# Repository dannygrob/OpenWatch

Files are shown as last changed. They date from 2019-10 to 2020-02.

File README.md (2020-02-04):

# OpenWatch
Open source watch based on [https://github.com/S-March/smarchWatch_PUBLIC](smarchWatch), da14683 ic. It uses some files Samson wrote, but most are heavily changed or created by me. I did not want to fork it, since it's a different watch (on the same pcb but with touch connector). Also started this repo just for myself but decided to share it.

It can connect to iOS devices and receive notifications. At the moment the project is still WIP.

Picture of the watch and os
Small video of the watch in action [found here](https://streamable.com/83sec)

It uses [this touchscreen](https://www.topfoison.com/Products-TF13016A-C.html). I ordered 10 samples from Topfoison on alibaba, but it's hard and expensive to get. Also the backlight is wired in series, but the pcb can only supply 3.2v parallel). I chose this display because it has a better layout for the connectors.
It does work with [this one](https://www.dhgate.com/product/1-3-inch-240-240-round-ips-tft-lcd-module/411021741.html#seo=WAP) but that won't fit the housing and can't fold nicely flat (in my batch of lcd's). If a better version will be found I'll update the pcb and housing.

There is no finished tutorial yet but you can find a getting started guide here:
[Getting started guide](https://github.com/dannygrob/OpenWatch/blob/master/OpenWatch%20getting%20started%20guide%5Bwip%5D.pdf)

It could be best to start with the [Development Kit USB](https://www.dialog-semiconductor.com/products/da14683-development-kit-usb) if you are totally new and don't want to start with a custom pcb. You do need a breakout for the LCD and connect it to the dev kit.

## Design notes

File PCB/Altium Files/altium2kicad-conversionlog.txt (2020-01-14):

Archive:  db/5355.zip
  inflating: db/5355/Actuators.SchDoc  
  inflating: db/5355/BLE.SchDoc      
  inflating: db/5355/Display.SchDoc  
  inflating: db/5355/Main.SchDoc     
  inflating: db/5355/Power.SchDoc    
  inflating: db/5355/Sensors.SchDoc  
  inflating: db/5355/smarchWatch_V5.BomDoc  
  inflating: db/5355/smarchWatch_V5.OutJob  
  inflating: db/5355/smarchWatch_V5.PcbDoc  
  inflating: db/5355/smarchWatch_V5.PrjPcb  
  inflating: db/5355/smarchWatch_V5.PrjPcbStructure  
Loading Actuators.SchDoc

Loading BLE.SchDoc

Loading Display.SchDoc

Loading Main.SchDoc

Loading Power.SchDoc

Loading Sensors.SchDoc

Loading smarchWatch_V5.PcbDoc

Done.
Handling Actuators-SchDoc/Root Entry/FileHeader.dat
Unhandled Record type without: 2  (#40)
Unhandled Record type without: 2  (#42)
This circle/arc is not part of a component, but KiCad does not support that. As a workaround we are creating a dummy component.
WARNING: Port orientation may be incorrect and thus unconnected - ports on the 'left' of wires may need moving and orientation flipping
WARNING: Port orientation may be incorrect and thus unconnected - ports on the 'left' of wires may need moving and orientation flipping
WARNING: Port orientation may be incorrect and thus unconnected - ports on the 'left' of wires may need moving and orientation flipping
WARNING: Port orientation may be incorrect and thus unconnected - ports on the 'left' of wires may need moving and orientation flipping
WARNING: Port orientation may be incorrect and thus unconnected - ports on the 'left' of wires may need moving and orientation flipping
Error: No ERC without position !  |LINENO=68||RECORD=22|IndexInSheet=52|OwnerPartId=-1|Location.X=345|Location.Y=430|Color=255|Orientation=1|Symbol=Thin Cross|IsActive=T|SuppressAll=T|UniqueID=SFFLRJFS
Error: No ERC without position !  |LINENO=69||RECORD=22|IndexInSheet=53|OwnerPartId=-1|Location.X=605|Location.Y=520|Color=255|Orientation=1|Symbol=Thin Cross|IsActive=T|SuppressAll=T|UniqueID=PAWUNZWO
Unhandled Record type without: 2  (#82)
Unhandled Record type without: 2  (#84)
Unhandled Record type without: 2  (#86)
Unhandled Record type without: 2  (#88)
Unhandled Record type without: 2  (#90)
Unhandled Record type without: 2  (#92)
Unhandled Record type without: 2  (#94)
Unhandled Record type without: 2  (#96)
Unhandled Record type without: 2  (#136)
Unhandled Record type without: 2  (#138)
Unhandled Record type without: 2  (#155)
Unhandled Record type without: 2  (#157)
WARNING: Port orientation may be incorrect and thus unconnected - ports on the 'left' of wires may need moving and orientation flipping
Unhandled Record type without: 2  (#186)
Unhandled Record type without: 2  (#188)
Unhandled Record type without: 2  (#190)
Unhandled Record type without: 2  (#192)
Unhandled Record type without: 2  (#194)
Unhandled Record type without: 2  (#196)
Unhandled Record type without: 2  (#198)
Unhandled Record type without: 2  (#200)
Unhandled Record type without: 2  (#202)
Unhandled Record type without: 2  (#204)
Unhandled Record type without: 2  (#206)
Unhandled Record type without: 2  (#208)
Unhandled Record type without: 2  (#210)
Unhandled Record type without: 2  (#212)
Unhandled Record type without: 2  (#214)
Unhandled Record type without: 2  (#216)
Unhandled Record type without: 2  (#218)
Unhandled Record type without: 2  (#220)
Unhandled Record type without: 2  (#230)
Unhandled Record type without: 2  (#232)
Unhandled Record type without: 2  (#248)
Unhandled Record type without: 2  (#250)
Handling BLE-SchDoc/Root Entry/FileHeader.dat
Unhandled Record type without: 2  (#41)
Unhandled Record type without: 2  (#43)
Unhandled Record type without: 2  (#45)
Unhandled Record type without: 2  (#47)
Unhandled Record type without: 2  (#49)
Unhandled Record type without: 2  (#51)
Unhandled Record type without: 2  (#53)
Unhandled Record type without: 2  (#55)
Unhandled Record type without: 2  (#92)
Unhandled Record type without: 2  (#94)
Unhandled Record type without: 2  (#121)
Unhandled Record type without: 2  (#123)
Unhandled Record type without: 2  (#145)
Unhandled Record type without: 2  (#147)
Unhandled Record type without: 2  (#166)
Unhandled Record type without: 2  (#168)
Unhandled Record type without: 2  (#190)
Unhandled Record type without: 2  (#192)
Unhandled Record type without: 2  (#213)
Unhandled Record type without: 2  (#215)
Unhandled Record type without: 2  (#234)
Unhandled Record type without: 2  (#236)
Unhandled Record type without: 2  (#271)
Unhandled Record type without: 2  (#273)
Unhandled Record type without: 2  (#294)
Unhandled Record type without: 2  (#296)
Unhandled Record type without: 2  (#315)
Unhandled Record type without: 2  (#317)
Unhandled Record type without: 2  (#343)
Unhandled Record type without: 2  (#345)
Unhandled Record type without: 2  (#367)
Unhandled Record type without: 2  (#369)
Error: No ERC without position !  |LINENO=397||RECORD=22|IndexInSheet=128|OwnerPartId=-1|Location.X=200|Location.Y=150|Color=255|Orientation=1|Symbol=Thin Cross|IsActive=T|SuppressAll=T|UniqueID=SCRABDOE
Error: No ERC without position !  |LINENO=398||RECORD=22|IndexInSheet=129|OwnerPartId=-1|Location.X=200|Location.Y=140|Color=255|Orientation=1|Symbol=Thin Cross|IsActive=T|SuppressAll=T|UniqueID=KIPODXKP
Unhandled Record type without: 2  (#400)
Unhandled Record type without: 2  (#402)
Unhandled Record type without: 2  (#421)
Unhandled Record type without: 2  (#423)
Unhandled Record type without: 2  (#441)
Unhandled Record type without: 2  (#443)
Unhandled Record type without: 2  (#492)
Unhandled Record type without: 2  (#494)
Unhandled Record type without: 2  (#496)
Unhandled Record type without: 2  (#498)
WARNING: Port orientation may be incorrect and thus unconnected - ports on the 'left' of wires may need moving and orientation flipping
WARNING: Port orientation may be incorrect and thus unconnected - ports on the 'left' of wires may need moving and orientation flipping
WARNING: Port orientation may be incorrect and thus unconnected - ports on the 'left' of wires may need moving and orientation flipping
WARNING: Port orientation may be incorrect and thus unconnected - ports on the 'left' of wires may need moving and orientation flipping
WARNING: Port orientation may be incorrect and thus unconnected - ports on the 'left' of wires may need moving and orientation flipping
WARNING: Port orientation may be incorrect and thus unconnected - ports on the 'left' of wires may need moving and orientation flipping
WARNING: Port orientation may be incorrect and thus unconnected - ports on the 'left' of wires may need moving and orientation flipping
WARNING: Port orientation may be incorrect and thus unconnected - ports on the 'left' of wires may need moving and orientation flipping
WARNING: Port orientation may be incorrect and thus unconnected - ports on the 'left' of wires may need moving and orientation flipping
Unhandled Record type without: 2  (#529)
Unhandled Record type without: 2  (#531)
Error: No ERC without position !  |LINENO=548||RECORD=22|IndexInSheet=191|OwnerPartId=-1|Location.X=490|Location.Y=200|Color=255|Orientation=1|Symbol=Thin Cross|IsActive=T|SuppressAll=T|UniqueID=GQLEGVTE
Error: No ERC without position !  |LINENO=549||RECORD=22|IndexInSheet=192|OwnerPartId=-1|Location.X=490|Location.Y=180|Color=255|Orientation=1|Symbol=Thin Cross|IsActive=T|SuppressAll=T|UniqueID=LDTXLNGJ
Error: No ERC without position !  |LINENO=554||RECORD=22|IndexInSheet=197|OwnerPartId=-1|Location.X=490|Location.Y=260|Color=255|Orientation=1|Symbol=Thin Cross|IsActive=T|SuppressAll=T|UniqueID=CXTTPFCG
Error: No ERC without position !  |LINENO=555||RECORD=22|IndexInSheet=198|OwnerPartId=-1|Location.X=490|Location.Y=250|Color=255|Orientation=1|Symbol=Thin Cross|IsActive=T|SuppressAll=T|UniqueID=WIQTXMIF
Error: No ERC without position !  |LINENO=558||RECORD=22|IndexInSheet=201|OwnerPartId=-1|Location.X=490|Location.Y=280|Color=255|Orientation=1|Symbol=Thin Cross|IsActive=T|SuppressAll=T|UniqueID=UENVZZXS
Error: No ERC without position !  |LINENO=559||RECORD=22|IndexInSheet=202|OwnerPartId=-1|Location.X=490|Location.Y=270|Color=255|Orientation=1|Symbol=Thin Cross|IsActive=T|SuppressAll=T|UniqueID=IYXEXPWA
Error: No ERC without position !  |LINENO=561||RECORD=22|IndexInSheet=204|OwnerPartId=-1|Location.X=490|Location.Y=290|Color=255|Orientation=1|Symbol=Thin Cross|IsActive=T|SuppressAll=T|UniqueID=BNRXXOTP
Error: No ERC without position !  |LINENO=563||RECORD=22|IndexInSheet=206|OwnerPartId=-1|Location.X=490|Location.Y=340|Color=255|Orientation=1|Symbol=Thin Cross|IsActive=T|SuppressAll=T|UniqueID=TIAOVCGG
Error: No ERC without position !  |LINENO=565||RECORD=22|IndexInSheet=208|OwnerPartId=-1|Location.X=490|Location.Y=320|Color=255|Orientation=1|Symbol=Thin Cross|IsActive=T|SuppressAll=T|UniqueID=DGXBEZZU
Error: No ERC without position !  |LINENO=569||RECORD=22|IndexInSheet=212|OwnerPartId=-1|Location.X=490|Location.Y=430|Color=255|Orientation=1|Symbol=Thin Cross|IsActive=T|SuppressAll=T|UniqueID=JFBMABUD
Error: No ERC without position !  |LINENO=570||RECORD=22|IndexInSheet=213|OwnerPartId=-1|Location.X=490|Location.Y=420|Color=255|Orientation=1|Symbol=Thin Cross|IsActive=T|SuppressAll=T|UniqueID=RORHNQZK
Error: No ERC without position !  |LINENO=572||RECORD=22|IndexInSheet=215|OwnerPartId=-1|Location.X=490|Location.Y=440|Color=255|Orientation=1|Symbol=Thin Cross|IsActive=T|SuppressAll=T|UniqueID=QYVFLALO
Error: No ERC without position !  |LINENO=574||RECORD=22|IndexInSheet=217|OwnerPartId=-1|Location.X=490|Location.Y=450|Color=255|Orientation=1|Symbol=Thin Cross|IsActive=T|SuppressAll=T|UniqueID=FMJIYKPS
Error: No ERC without position !  |LINENO=577||RECORD=22|IndexInSheet=220|OwnerPartId=-1|Location.X=490|Location.Y=470|Color=255|Orientation=1|Symbol=Thin Cross|IsActive=T|SuppressAll=T|UniqueID=VTZWOPYF
Error: No ERC without position !  |LINENO=579||RECORD=22|IndexInSheet=222|OwnerPartId=-1|Location.X=490|Location.Y=500|Color=255|Orientation=1|Symbol=Thin Cross|IsActive=T|SuppressAll=T|UniqueID=LDOMFXJQ
Unhandled Record type without: 2  (#594)
Unhandled Record type without: 2  (#596)
Unhandled Record type without: 2  (#598)
Unhandled Record type without: 2  (#600)
Unhandled Record type without: 2  (#602)
Unhandled Record type without: 2  (#604)
Unhandled Record type without: 2  (#606)
Unhandled Record type without: 2  (#608)
Unhandled Record type without: 2  (#610)
Unhandled Record type without: 2  (#612)
Unhandled Record type without: 2  (#614)
Unhandled Record type without: 2  (#616)
Unhandled Record type without: 2  (#618)
Unhandled Record type without: 2  (#620)
Unhandled Record type without: 2  (#622)
Unhandled Record type without: 2  (#624)
Unhandled Record type without: 2  (#626)
Unhandled Record type without: 2  (#628)
Unhandled Record type without: 2  (#630)
Unhandled Record type without: 2  (#632)
Unhandled Record type without: 2  (#634)
Unhandled Record type without: 2  (#636)
Unhandled Record type without: 2  (#638)
Unhandled Record type without: 2  (#640)
Unhandled Record type without: 2  (#642)
Unhandled Record type without: 2  (#644)
Unhandled Record type without: 2  (#646)
Unhandled Record type without: 2  (#648)
Unhandled Record type without: 2  (#650)
Unhandled Record type without: 2  (#652)
Unhandled Record type without: 2  (#654)
Unhandled Record type without: 2  (#656)
Unhandled Record type without: 2  (#658)
Unhandled Record type without: 2  (#660)
Unhandled Record type without: 2  (#662)
Unhandled Record type without: 2  (#664)
Unhandled Record type without: 2  (#666)
Unhandled Record type without: 2  (#668)
Unhandled Record type without: 2  (#670)
Unhandled Record type without: 2  (#672)
Unhandled Record type without: 2  (#674)
Unhandled Record type without: 2  (#676)
Unhandled Record type without: 2  (#678)
Unhandled Record type without: 2  (#680)
Unhandled Record type without: 2  (#682)
Unhandled Record type without: 2  (#684)
Unhandled Record type without: 2  (#686)
Unhandled Record type without: 2  (#688)
Unhandled Record type without: 2  (#690)
Unhandled Record type without: 2  (#692)
Unhandled Record type without: 2  (#694)
Unhandled Record type without: 2  (#696)
Unhandled Record type without: 2  (#698)
Unhandled Record type without: 2  (#700)
Unhandled Record type without: 2  (#702)
Unhandled Record type without: 2  (#704)
Unhandled Record type without: 2  (#706)
Unhandled Record type without: 2  (#708)
Unhandled Record type without: 2  (#710)
Unhandled Record type without: 2  (#712)
Unhandled Record type without: 2  (#714)
WARNING: Port orientation may be incorrect and thus unconnected - ports on the 'left' of wires may need moving and orientation flipping
WARNING: Port orientation may be incorrect and thus unconnected - ports on the 'left' of wires may need moving and orientation flipping
Unhandled Record type without: 2  (#728)
Unhandled Record type without: 2  (#738)
Unhandled Record type without: 2  (#750)
Unhandled Record type without: 2  (#760)
Unhandled Record type without: 2  (#773)
Unhandled Record type without: 2  (#786)
Unhandled Record type without: 2  (#796)
Unhandled Record type without: 2  (#817)
Unhandled Record type without: 2  (#819)
Unhandled Record type without: 2  (#834)
Unhandled Record type without: 2  (#836)
Unhandled Record type without: 2  (#855)
Unhandled Record type without: 2  (#857)
Unhandled Record type without: 2  (#882)
Error: No ERC without position !  |LINENO=894||RECORD=22|IndexInSheet=277|OwnerPartId=-1|Location.X=490|Location.Y=380|Color=255|Orientation=1|Symbol=Thin Cross|IsActive=T|SuppressAll=T|UniqueID=HJWXARXT
Handling Display-SchDoc/Root Entry/FileHeader.dat
Unhandled Record type without: 2  (#40)
Unhandled Record type without: 2  (#42)
Unhandled Record type without: 2  (#44)
Unhandled Record type without: 2  (#46)
Unhandled Record type without: 2  (#48)
Unhandled Record type without: 2  (#50)
Unhandled Record type without: 2  (#52)
Unhandled Record type without: 2  (#54)
Unhandled Record type without: 2  (#56)
Unhandled Record type without: 2  (#58)
Unhandled Record type without: 2  (#60)
Unhandled Record type without: 2  (#62)
Unhandled Record type without: 2  (#64)
Unhandled Record type without: 2  (#66)
Unhandled Record type without: 2  (#68)
Unhandled Record type without: 2  (#70)
Unhandled Record type without: 2  (#72)
Unhandled Record type without: 2  (#74)
Unhandled Record type without: 2  (#85)
Unhandled Record type without: 2  (#87)
This circle/arc is not part of a component, but KiCad does not support that. As a workaround we are creating a dummy component.
WARNING: Port orientation may be incorrect and thus unconnected - ports on the 'left' of wires may need moving and orientation flipping
WARNING: Port orientation may be incorrect and thus unconnected - ports on the 'left' of wires may need moving and orientation flipping
WARNING: Port orientation may be incorrect and thus unconnected - ports on the 'left' of wires may need moving and orientation flipping
WARNING: Port orientation may be incorrect and thus unconnected - ports on the 'left' of wires may need moving and orientation flipping
WARNING: Port orientation may be incorrect and thus unconnected - ports on the 'left' of wires may need moving and orientation flipping
Error: No ERC without position !  |LINENO=116||RECORD=22|IndexInSheet=56|OwnerPartId=-1|Location.X=205|Location.Y=395|Color=255|Orientation=1|Symbol=Thin Cross|IsActive=T|SuppressAll=T|UniqueID=SFFLRJFS
Error: No ERC without position !  |LINENO=117||RECORD=22|IndexInSheet=57|OwnerPartId=-1|Location.X=390|Location.Y=485|Color=255|Orientation=1|Symbol=Thin Cross|IsActive=T|SuppressAll=T|UniqueID=PAWUNZWO
Handling Main-SchDoc/Root Entry/FileHeader.dat
Handling Power-SchDoc/Root Entry/FileHeader.dat
WARNING: Port orientation may be incorrect and thus unconnected - ports on the 'left' of wires may need moving and orientation flipping
Unhandled Record type without: 2  (#42)
Unhandled Record type without: 2  (#44)
Unhandled Record type without: 2  (#46)
Unhandled Record type without: 2  (#48)
Unhandled Record type without: 2  (#50)
Unhandled Record type without: 2  (#52)
Unhandled Record type without: 2  (#62)
Unhandled Record type without: 2  (#64)
Unhandled Record type without: 2  (#66)
Unhandled Record type without: 2  (#68)
Unhandled Record type without: 2  (#70)
Unhandled Record type without: 2  (#72)
Unhandled Record type without: 2  (#74)
Unhandled Record type without: 2  (#76)
Unhandled Record type without: 2  (#114)
Unhandled Record type without: 2  (#116)
Unhandled Record type without: 2  (#133)
Unhandled Record type without: 2  (#135)
Unhandled Record type without: 2  (#154)
Unhandled Record type without: 2  (#156)
Error: No ERC without position !  |LINENO=174||RECORD=22|IndexInSheet=52|OwnerPartId=-1|Location.X=565|Location.Y=345|Color=255|Orientation=1|Symbol=Thin Cross|IsActive=T|SuppressAll=T|UniqueID=ELZIAFNV
Unhandled Record type without: 2  (#176)
Unhandled Record type without: 2  (#178)
Unhandled Record type without: 2  (#197)
Unhandled Record type without: 2  (#199)
Unhandled Record type without: 2  (#229)
Unhandled Record type without: 2  (#231)
Unhandled Record type without: 2  (#247)
Unhandled Record type without: 2  (#249)
Unhandled Record type without: 2  (#272)
Unhandled Record type without: 2  (#274)
Unhandled Record type without: 2  (#289)
Unhandled Record type without: 2  (#292)
Unhandled Record type without: 2  (#302)
Unhandled Record type without: 2  (#304)
Unhandled Record type without: 7  (#306)
Unhandled Record type without: 7  (#312)
Handling Sensors-SchDoc/Root Entry/FileHeader.dat
WARNING: Port orientation may be incorrect and thus unconnected - ports on the 'left' of wires may need moving and orientation flipping
WARNING: Port orientation may be incorrect and thus unconnected - ports on the 'left' of wires may need moving and orientation flipping
WARNING: Port orientation may be incorrect and thus unconnected - ports on the 'left' of wires may need moving and orientation flipping
Unhandled Record type without: 2  (#52)
Unhandled Record type without: 2  (#54)
Unhandled Record type without: 2  (#73)
Unhandled Record type without: 2  (#75)
Unhandled Record type without: 2  (#94)
Unhandled Record type without: 2  (#96)
Unhandled Record type without: 2  (#98)
Unhandled Record type without: 2  (#100)
Unhandled Record type without: 2  (#102)
Unhandled Record type without: 2  (#104)
Unhandled Record type without: 2  (#106)
Unhandled Record type without: 2  (#108)
Unhandled Record type without: 2  (#110)
Unhandled Record type without: 2  (#112)
Unhandled Record type without: 2  (#114)
Unhandled Record type without: 2  (#116)
Unhandled Record type without: 2  (#118)
Unhandled Record type without: 2  (#120)
Unhandled Record type without: 2  (#122)
Unhandled Record type without: 2  (#124)
Error: No ERC without position !  |LINENO=137||RECORD=22|IndexInSheet=62|OwnerPartId=-1|Location.X=425|Location.Y=470|Color=255|Orientation=1|Symbol=Thin Cross|IsActive=T|SuppressAll=T|UniqueID=VVGRMCXU
Error: No ERC without position !  |LINENO=138||RECORD=22|IndexInSheet=63|OwnerPartId=-1|Location.X=425|Location.Y=460|Color=255|Orientation=1|Symbol=Thin Cross|IsActive=T|SuppressAll=T|UniqueID=KOKTSHZL
Error: No ERC without position !  |LINENO=139||RECORD=22|IndexInSheet=64|OwnerPartId=-1|Location.X=425|Location.Y=450|Color=255|Orientation=1|Symbol=Thin Cross|IsActive=T|SuppressAll=T|UniqueID=GMMDXBIB
Error: No ERC without position !  |LINENO=140||RECORD=22|IndexInSheet=65|OwnerPartId=-1|Location.X=425|Location.Y=430|Color=255|Orientation=1|Symbol=Thin Cross|IsActive=T|SuppressAll=T|UniqueID=RCUAUGDQ
Error: No ERC without position !  |LINENO=141||RECORD=22|IndexInSheet=66|OwnerPartId=-1|Location.X=425|Location.Y=420|Color=255|Orientation=1|Symbol=Thin Cross|IsActive=T|SuppressAll=T|UniqueID=SAWKDOCT
Unhandled Record type without: 2  (#143)
Unhandled Record type without: 2  (#145)
Unhandled Record type without: 2  (#164)
Unhandled Record type without: 2  (#166)
WARNING: Port orientation may be incorrect and thus unconnected - ports on the 'left' of wires may need moving and orientation flipping
Handling smarchWatch_V5-PcbDoc/Root Entry/FileHeader.dat
Handling Actuators.SchDoc
Handling BLE.SchDoc
Handling Display.SchDoc
Handling Main.SchDoc
Handling Power.SchDoc
Handling Sensors.SchDoc
Handling smarchWatch_V5-PcbDoc/Root Entry/Board6/Data.dat
ASCII-smarchWatch_V5-PcbDoc.PcbDoc exists?
Writing to smarchWatch_V5-PcbDoc/Root Entry/Board6/Data.dat.txt
Writing to smarchWatch_V5-PcbDoc/Root Entry/Models/Data.dat.txt
Writing to smarchWatch_V5-PcbDoc/Root Entry/UniqueIDPrimitiveInformation/Data.dat.txt
Writing to smarchWatch_V5-PcbDoc/Root Entry/Rules6/Data.dat.txt
Writing to smarchWatch_V5-PcbDoc/Root Entry/Classes6/Data.dat.txt
Writing PCB to smarchWatch_V5-PcbDoc.kicad_pcb
Writing to smarchWatch_V5-PcbDoc/Root Entry/Nets6/Data.dat.txt
Writing to smarchWatch_V5-PcbDoc/Root Entry/Components6/Data.dat.txt
Pads6...
Writing to smarchWatch_V5-PcbDoc/Root Entry/ComponentBodies6/Data.dat.txt
NOT FOUND: displayAssembly.wrl
NOT FOUND: DF37NB-24DS-04V.wrl
NOT FOUND: pcb_connector_800-10-002-30-507101.wrl
NOT FOUND: RJD2430C1ST1.wrl
NOT FOUND: LIS3DH v4.wrl
NOT FOUND: C0720B001F v18.wrl
NOT FOUND: 7M-16.000MEEQ-T v5.wrl
NOT FOUND: 9HT11-32.768KDZB-T v3.wrl
NOT FOUND: DA14683 v6.wrl
NOT FOUND: SODFL100X40-2N.wrl
NOT FOUND: SON65P230X95-8N.wrl
NOT FOUND: SON127P600X80_HS-9N.wrl
NOT FOUND: SON50P150X80-6N.wrl
Writing to smarchWatch_V5-PcbDoc/Root Entry/ShapeBasedComponentBodies6/Data.dat.txt
Writing to smarchWatch_V5-PcbDoc/Root Entry/Components6/Data.dat.txt
Where did the model come from? componentid: 0
Where did the model come from? componentid: 1
Where did the model come from? componentid: 2
Where did the model come from? componentid: 3
Where did the model come from? componentid: 4
Where did the model come from? componentid: 5
Where did the model come from? componentid: 7
Where did the model come from? componentid: 8
Where did the model come from? componentid: 9
Where did the model come from? componentid: 10
Where did the model come from? componentid: 18
Where did the model come from? componentid: 19
Where did the model come from? componentid: 20
Where did the model come from? componentid: 21
Where did the model come from? componentid: 22
Where did the model come from? componentid: 23
Where did the model come from? componentid: 24
Where did the model come from? componentid: 25
Where did the model come from? componentid: 26
Where did the model come from? componentid: 27
Where did the model come from? componentid: 28
Where did the model come from? componentid: 29
Where did the model come from? componentid: 30
Where did the model come from? componentid: 31
Where did the model come from? componentid: 32
Where did the model come from? componentid: 33
Where did the model come from? componentid: 34
Where did the model come from? componentid: 35
Where did the model come from? componentid: 36
Where did the model come from? componentid: 37
Where did the model come from? componentid: 38
Where did the model come from? componentid: 39
Where did the model come from? componentid: 40
Where did the model come from? componentid: 41
Where did the model come from? componentid: 42
Where did the model come from? componentid: 43
Where did the model come from? componentid: 44
Where did the model come from? componentid: 45
Where did the model come from? componentid: 46
Where did the model come from? componentid: 47
Where did the model come from? componentid: 48
Where did the model come from? componentid: 49
Where did the model come from? componentid: 50
Where did the model come from? componentid: 51
Where did the model come from? componentid: 52
Where did the model come from? componentid: 53
Writing to smarchWatch_V5-PcbDoc/Root Entry/Arcs6/Data.dat.txt
Writing to smarchWatch_V5-PcbDoc/Root Entry/Vias6/Data.dat.txt
Writing to smarchWatch_V5-PcbDoc/Root Entry/Polygons6/Data.dat.txt
Writing to smarchWatch_V5-PcbDoc/Root Entry/Tracks6/Data.dat.txt
Writing to smarchWatch_V5-PcbDoc/Root Entry/FileVersionInfo/Data.dat.txt
Writing to smarchWatch_V5-PcbDoc/Root Entry/Fills6/Data.dat.txt
Writing to smarchWatch_V5-PcbDoc/Root Entry/Regions6/Data.dat.txt
Texts6...

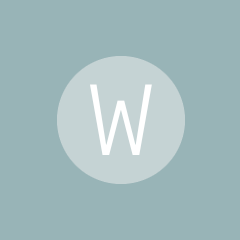
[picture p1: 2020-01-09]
Images/ZBOOTSCREEN.bmp

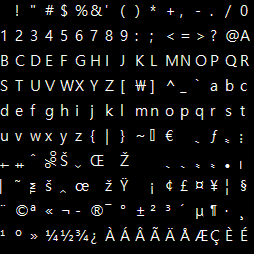
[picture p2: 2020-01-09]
Images/FONT.bmp

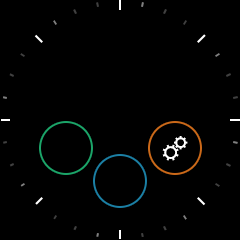
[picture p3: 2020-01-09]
Images/WATCHFACE.bmp

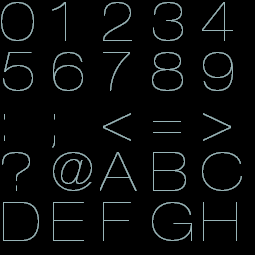
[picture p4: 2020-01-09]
Images/LIGHTFONT.bmp

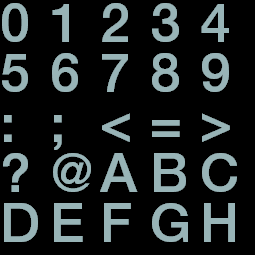
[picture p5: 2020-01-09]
Images/MEDIUMFONT.bmp

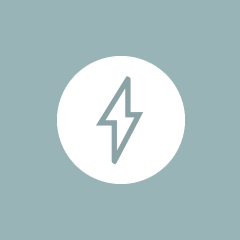
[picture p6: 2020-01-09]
Images/CHARGING.bmp

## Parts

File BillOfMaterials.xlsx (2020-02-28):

Comment | Description | Designator | Quantity | Part number | Digikey Number
10K | 0603 Resistor | R1, R3, R4, R5, R11 | 5 | RC0603FR-0710KL | 311-10.0KHRCT-ND
10uF | 0603 Capacitor | C2, C10, C11, C12, C15 | 5 | GRM188R61A106KE69D | 490-10474-1-ND
4.7uF | 0603 Capacitor | C3, C8, C9, C13 | 4 | CL10A475KP8NNNC | 1276-1044-1-ND
1uF | 0603 Capacitor | C4, C6, C7 | 3 | CL10B105KP8NNNC | 1276-1946-1-ND
100nF | 0603 Capacitor | C1, C5, C14 | 3 | CC0603KRX7R9BB104 | 311-1344-1-ND
5.1M | 0603 Resistor | R8, R9 | 2 | RC0603JR-075M1L | 311-5.1MGRCT-ND
330 Ohm | 0603 Resistor | R6 | 1 | RC0603FR-07330RL | 311-330HRCT-ND
ECH8693R-TL-W | Mosfet Array 2 N-Channel (Dual) Common Drain 24V 14A 1.4W Surface Mount SOT-28FL/ECH8 | Q1, Q2 | 2 | ECH8693R-TL-W | ECH8693R-TL-WOSCT-ND
0 Ohm | 0603 Resistor | R13, R10 | 2 | RC0603JR-070RL | 311-0.0GRCT-ND
0.1 Ohm | 0603 Resistor | R2 | 1 | RU1608FR100CS | 1276-6155-1-ND
0.39 Ohm | 0805 Resistor | R12 | 1 | RL0805FR-7W0R39L | 311-.39LUCT-ND
2.2K | 0603 Resistor | R7 | 1 | RC0603FR-072K2L | 311-2.20KHRCT-ND
7M-16.000MEEQ-T | 16MHz ±10ppm Crystal 10pF 80 Ohms 4-SMD, No Lead | Y2 | 1 | 7M-16.000MEEQ-T | 887-1319-1-ND
9HT11-32.768KDZB-T | 32.768kHz ±20ppm Crystal 6pF 90 kOhms 2-SMD, No Lead | Y1 | 1 | 9HT11-32.768KDZB-T | 887-2616-1-ND
800-10-002-30-507101 | 2 Position Spring Mating Target Connector Surface Mount | P1 | 1 | 800-10-002-30-507101 | 1212-1446-ND
AML130A2402A | AML130A2402A Round 1.3" TFT Display | U1 | 1 | AML130A2402A | Dhgate.com
BQ29700DSER | Battery Battery Protection IC Lithium-Ion/Polymer 6-WSON (1.5x1.5) | U5 | 1 | BQ29700DSER | 296-43985-1-ND
C0720B001F | DC Motor Vibration, ERM 10000 RPM 3VDC | M1 | 1 | C0720B001F | 1670-1000-ND
CKP2012NR47M-T | Inductor_0805 | L1 | 1 | CKP2012NR47M-T | 587-2768-1-ND
DA14683 | SmartBond DA14683 Single-chip high-security Bluetooth 5 solution with expandable memory | U3 | 1 | DA14683-00000A92 | DA14683-00000A92CT-ND
ESD9B5.0ST5G | TVS DIODE 5V SOD923 | D1 | 1 | ESD9B5.0ST5G | ESD9B5.0ST5GOSCT-ND
LIS3DH | LIS3DH ACCEL 2-16G I2C/SPI 16LGA | U2 | 1 | LIS3DHTR | 497-10613-1-ND
RJD2430C1ST1 | Coin, 24.5mm 3.7V Lithium-Ion Battery Rechargeable (Secondary) 110mAh | BAT1 | 1 | RJD2430C1ST1 | 1572-1630-ND
W25Q128JVPIQ | FLASH - NOR Memory IC 128Mb (16M x 8) SPI - Quad I/O, QPI, DTR 133MHz 8-WSON (6x5) | U4 | 1 | W25Q128JVPIQ TR | W25Q128JVPIQCT-ND
PCB | PCB | N/A | 1 | N/A | N/A
Touch connector | DF37C-10DP-0.4V |  | 1 | DF37C-10DP-0.4V(51) | DF37C-10DP-0.4V-51-ND

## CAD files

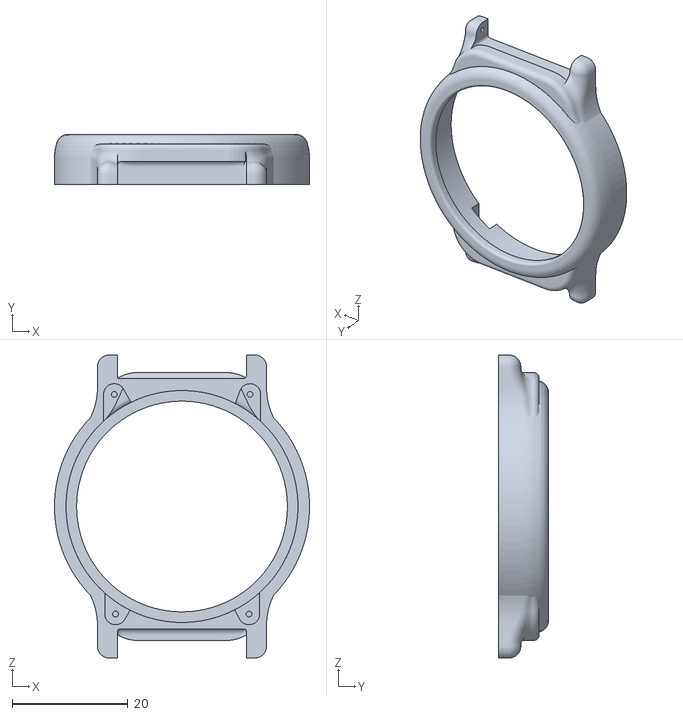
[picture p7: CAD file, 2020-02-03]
Housing/top_v8.stl
44.0 x 8.65 x 52.2

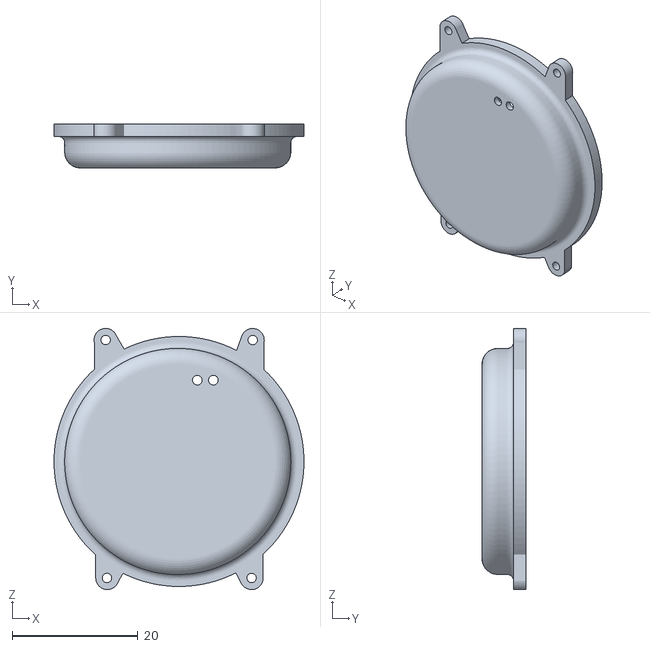
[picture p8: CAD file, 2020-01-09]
Housing/bottom_v9.stl
39.8 x 7.00 x 41.6

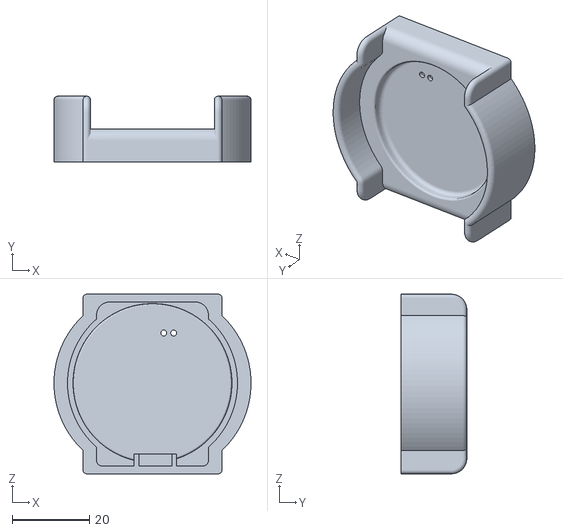
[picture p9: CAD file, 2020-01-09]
Housing/dock1.stl
51.0 x 17.0 x 46.5

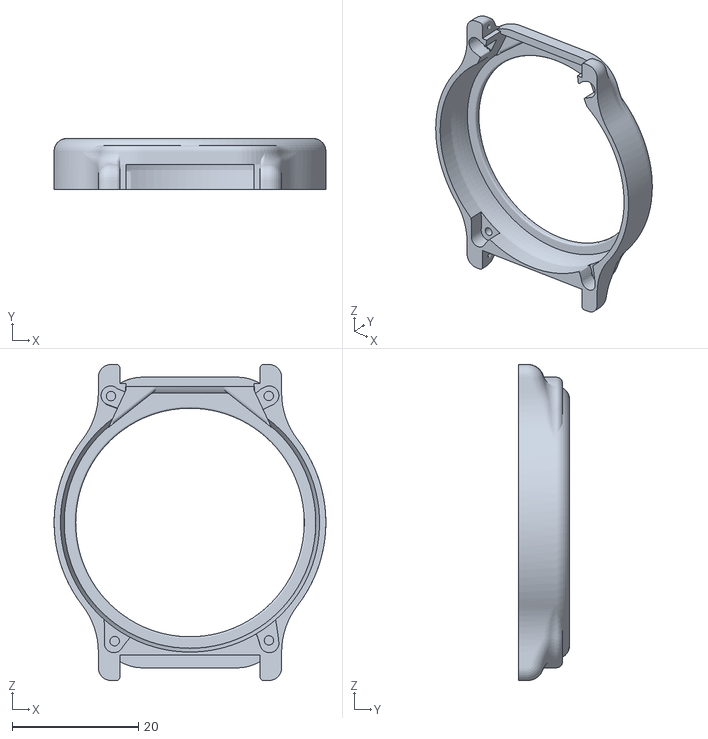
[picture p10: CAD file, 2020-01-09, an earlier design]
Housing/top_v7.stl
43.0 x 8.10 x 50.0

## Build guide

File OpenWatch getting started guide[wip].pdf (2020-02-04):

## OpenWatch getting started guide

Written by Danny Grob
Contents
- Introduction
- Making the PCB
- Soldering tips
- Connecting to the PCB
- Setting up the software
- Copying bitmap files

Introduction
This project is based on the Dialog Semi SmartBond DA14683 microcontroller. It is an ARM-Cortex-M0 processor with BLE 5.0 build-in.

Making the PCB
You can order a pcb from a manufacturer of your choice, like jlcpcb or pcbway. It’s recommended to order a stencil too.

To make the pcb you have to upload a zip file that includes the Gerber and NC Drill folders. You can setup the parameters like the guide below

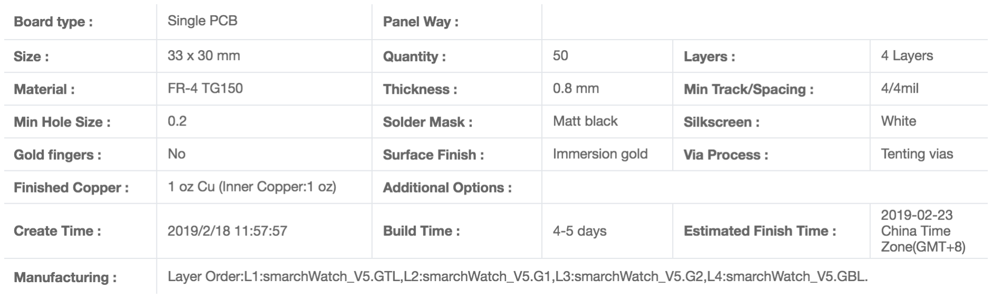
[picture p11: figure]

Soldering tips

[todo?]

Connecting to the pcb

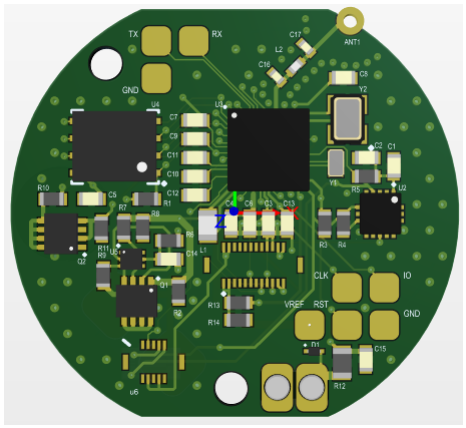
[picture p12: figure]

Connect the VBUS and GND to a 5v supply. This is needed so the mosfet opens and starts up the power. Also connect your battery. For debugging it’s nice to have an on-off switch in line to reset. You connect the JLink pins to the pcb. Either create a custom connector for this to speed up the development time, or just solder it on.

VTref
SWDIO/TMS
SWCLK/TCK
TDI
nRESET
GND

VREF
IO
CLK
RST
GND

To have debugger output you can use a serial to usb converter and connect the TX and RX (and GND).

Now the smart snippets studio should recognize the microcontroller.

Setting up the software
Download the Dialog Semi DA14683 SDK Install SmartSnippetsStudio found here (https://www.dialog-semiconductor.com/products/connectivity/bluetooth-low-energy/smartbond-da14682-and-da14683) , scroll down for your platform. Follow the getting started guide found here (https://www.dialog-semiconductor.com/sites/default/files/um-b-047-da1468x_getting_started_7v0.pdf)

Start the smart snippets studio after you’ve installed it. Make sure that you have the right SDK selected..

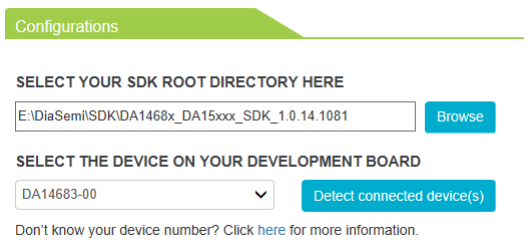
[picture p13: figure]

When clicking ‘detect connected devices’ your pcb should show up if it’s connected right. If not, check your connections, and make sure the pcb is powered from battery and 5v on the charge pins.

Project files
Checkout the git: https://github.com/dannygrob/OpenWatch . You can download everything as a zip file, or clone it.

Copy or move the ‘Software’ folder to (this is for the sdk references):

[install folder]\SDK\DA1468x_DA15xxx_SDK_1.0.14.1081\projects\dk_apps\ble_profiles\

Click the ‘Import test projects in workspace’ button and select the “software” folder you just created. From the guide linked above you should already have imported the ‘scripts’ folder. This is needed to upload the firmware.

The files in the ‘SDK Files’ folder should be copied in their right locations. The base
folder is: E:\DiaSemi\SDK\DA1468x_DA15xxx_SDK_1.0.14.1081\sdk\bsp\
Everything should follow the same structure, so for example platform_devices.h should go into sdk\bsp\adapters\include\. This overwrites the old one, you can make a backup if you want or just transfer the changes (some devices where added)

You are now ready to build the project and upload it to the board. You can upload it using the ‘program_qspi_jtag’ script. It should upload but the graphics are still missing.

Copying the bitmap files

The bitmap files were generated using Samson March’s Bitmap tool. These need to be uploaded into the right partition on the board’s flash ic. This can be done using the “SmartSnippets Toolbox”. Select your board from the middle column (if it’s not there it’s not connected) and press ‘open’.

Press the ‘connect’ button below the partitions section. After it connected correctly press ‘read’. It should now show something like this:

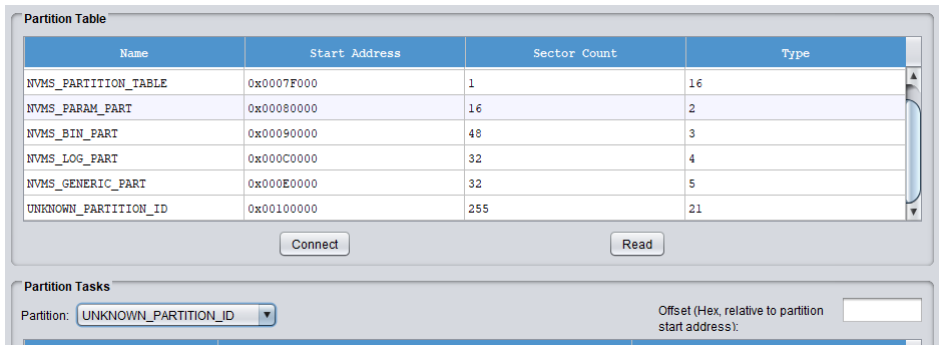
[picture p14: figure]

Make sure that there is an ‘UNKNOWN_PARTITION_ID’. If it is not there you either did not copy the “partition_table.h” file to the 16M folder in config in the SDK, or the program did not run before. The code needs to run on the board 1 time to setup the partitions. Select the UNKNOWN_PARTITION_ID in the partition tasks section.

Now select the “pictureFiles.bin” file from the bitmaps folder in the ‘select a file to burn or verify against’ section on the left of the screen. Press the ‘burn’ button on the bottom of the middle section to burn it to the flash. It should finish without errors.

You can now connect the display if you did not already and reset it. To reset without a reset button you can use ‘Segger Ozone’ and select the jlink programmer on SWD and load the ‘bin’ file that was generated when you compiled the code. This is not needed on the USB dev kit as it has a reset button.

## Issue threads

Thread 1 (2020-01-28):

PCB and Screen Sources

d3mon187, 2020-01-28:
Hey Danny, great to see some more development on this and the addition of a touch screen.  Checking out your Altium files, it looks like a new pcb is needed with the new lines and a spot to connect the touchscreen.  Have you found a good source for getting these?  Also, I had a bit of trouble tracking down a good source for the screen beyond contacting the manufacturer directly.  Did you find anyone selling it directly?

Thanks! I look forward to helping with programming once I actually get this $1000 budget smartwatch working.  Oh, and please be sure to post up some detailed tutorials.  I'm going to need them!

dannygrob, 2020-01-28:
Hi!

Yeah, you need a new pcb. Although my first version just had the connector wired up to the original smarchwatch pcb that was a hassle...

You can order it from https://jlcpcb.com (like I did), it cost me $17 for 10 pcbs and $16 shipping to the Netherlands. (I havn't even ordered it yet...)

You can use the original board parameters
https://github.com/S-March/smarchWatch_PUBLIC/blob/master/PCB%20Files/Watch/Board%20parameters.png

The LCD with touch is a bit hard. You can buy this one for testing (but as I said, the connector will not fold)
https://www.aliexpress.com/item/32920192414.html

I contacted the manufacturer directly on alibaba and payed $10 per LCD. It was not super difficult. If more people want to build this we can def. buy more at once and get a better price.
Here is the one I used:
https://www.alibaba.com/product-detail/TFT-LCD-Round-1-3inch-touch_62280453668.html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

d3mon187, 2020-01-28:
Awesome, wish I'd seen that jlcpcb site yesterday before I ordered a stencil.  Attempted my first solder by hand applying solder with a 22ga needle, and then heating it up with a hot air reflow gun.  Unfortunately it was a bit of a disaster.  connections on the screen connector had plenty of bridged pins, and I'm sure the situation under the dialog chip is probably the same.  I've got to wait for 0.39 ohm resistors anyway, so I'm hoping I'll have better luck on the second shot with a stencil.  Unfortunately the original BOM has a part number for a 390ohm resistor, so everything is on hold until then.

d3mon187, 2020-01-31:
Managed to get the pcb ordered from jlcpcb.  Says it's in production, but might be a while according to the banner saying they're affected by the coronavirus outbreak.  Ended up being about $50 total shipped including a stencil and 10pcbs.  Once you configure the settings it tends to add a bit.  Also waiting on hearing back from the screen manufacturer.  Hoping to get some clarification on the difference between TF13016C and the TF13016A-C.  Eventually I would like to start looking at 1.2 inch displays to try and start scaling down the size of the watch as much as possible.

dannygrob, 2020-02-01:
Hi

Nice to hear you ordered the pcb with the stencil, let me know when you get them!

I did forgot something. I had ordered TF13016A-C and the backlight did not work. That's because the LED's are in series instead of in paralel on the other lcd. I had both so I could swap the backlight but that was not ideal. I asked Topfoison to make them paralel but that would mean a custom order and make it very expensive. I'd recommend buying [these](https://www.aliexpress.com/item/32920192414.html) at first.

Soldering without the stencil and solder paste is challenging! You need to be very capable :) Even with stencil you need to take your time. Good luck :)

d3mon187, 2020-02-01:
Good to know about the Topfoison screen.  I'll do some hunting to see if I can find another better screen for the project.  I'll try the Surenoo for now.  Someone mentioned in the reviews that they were able to get it to bend, so maybe they fixed it or you got a bad batch.

I just printed your casing and charger dock, and I'm continually impressed by how much extra you've put into the project so far.  Love the updated design and sleekness.  I think you might have a wrong version uploaded though, because the top and bottom pieces of the watch housing do not match up on their screw tabs.  It's hard to tell without being able to join them, but did you have to increase the thickness of the watch to fit the touch screen, and are you still using the watch glass over the touch screen?

Very cool video!  I had no idea you had advanced that far on the UI.   Looking pretty legit!  Do you have it working for android?  I haven't even begun looking at that part of the project, but I can't imagine that will be too difficult.  iOS is usually 10x harder to get things working in from my experience.

dannygrob, 2020-02-01:
If the old screen can bend I think that one is preferred. I had a case made for that one, I can always change the current one back!

The trick about my prints is that I use an SLA printer with resin to get super high res results (Longer orange 10). I did print the dock with a normal ultimaker FDM. I don't think a normal fdm printer can print this case correctly, as the screen slides in very tightly and it has a lot of overhangs that need to be precise. I had to make a lot of little adjustments. My bottom and top line up perfectly, I'll check if I got the right files in the repo, thanks!

It uses the apple bluetooth protocol ANCS right now, used from some dialog semi example by samson. The nice thing about this is that all you need to do is pair the watch and you'll receive messages right away, this works great. You don't need an app. For android you'd probably need one, but that could be made. I am a mobile dev by day :)

It's nice that someone else besides me is interested in this, also motivates me to finish it!

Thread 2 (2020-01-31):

Programming

d3mon187, 2020-01-31:
Hey @dannygrob , so I'm kind of stuck at the moment on programming.  I purchased the Development Kit USB you linked to, setup the software, and even managed to build the original SmarchWatch project and load it to run on the Development Kit USB itself after switching the jumper to 3v.  No idea what running it on the usb gets someone since it doesn't have a screen, but I can guess it's working by seeing that it broadcasts a smarchwatch bluetooth signal.

My question is, how do I connect the Development Kit USB to the pcb, or am I not supposed to?  I realize you might not have messed with the dev kit usb, but any help you can give in figuring it out would mean the world to me!

If you look at the [schematic](https://www.dialog-semiconductor.com/sites/default/files/da14683_usb_kit_vc.pdf) the board has some holes for header pins at MIKROBUS & GENERAL
PURPOSE CONNECTORS section.  There's a RST, GND, and CLK in J6.  Not sure what SWDIO on the pcb would connect to?  Also, do you just solder temporary headers to the board, connect wires directly, or is there something simpler I'm missing?

There's a user manual for the device here - https://www.dialog-semiconductor.com/sites/default/files/um-b-094_da14683_usb_kit_rev_1.0.pdf if it helps.

Thanks!

dannygrob, 2020-02-01:
Hi!

I do use the devkit usb. You should see it as a seperate unit that replaces the custom pcb. It has the same dialog semi micro, and build-in serial port for debugging all over usb. It speeds up development and testing code as you can just plug it in. You can even connect the display if you have a breakout board (i got one with my display) to the i2c connection on the devkit

SWDIO on the pcb is to connect it to a JLink mini programmer that replaces the usb part on the dev kit. That way you can load code. The rx tx are for the com port to debug, but you need a ttl serial converter to usb for that.

I really want to make a step by step guide to get started for this, as once you know how to connect it, it is really doable. But a very steep learning curve to start! I'll try harder to find some time for this.

https://imgur.com/a/XhRLSg0

d3mon187, 2020-02-01:
Thanks for answering all my questions!  I'm a decent programmer, but know very little about the hardware side.  I've always wanted to build my own electronics though, and this seems like just the project to start with. I don't want to be annoying, but I feel like I'm at that exciting point where I feel so close to getting it working finally!

Ok, so devkit is nice to have for development, but I need a [jlink mini (?)](https://www.amazon.com/gp/product/B0758XRMTF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) in order to program the custom pcb.  That sure would have been nice if they made it so the devkit could do both!

Does this mean I'm going to run into the issue of needing to connect vref?  I saw that you had mentioned needing to connect vref or the like at R6.  Is that still necessary, and by doing that am I supposed to connect a wire to the resistor at R6, or ?  Sorry if that's a dumb question.  I see you've added pads to your new pcb to make it easier.

dannygrob, 2020-02-01:
Hi,

Yes that's the right programmer you linked there. I used that one to program the pcb. The VREF needs to connect to vbat indeed (at least from what I found) to make the smartsnippets software detect it. The pad I added should help yes!

Which pcb did you order, the original SmarchWatch or my modified version? I did mod the PCB but I havn't ordered it myself yet. I wanted to go over it 1 more time to see if I did not mess something up.

No problem about all these questions. Feel free to e-mail me too if you feel your question is not helping other people, we can communicate more quickly

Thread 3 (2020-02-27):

Bill of Materials

exploshot, 2020-02-27:
Hello, is the Bill of Materials the same or did you add or change something (except Battery or Screen)?

dannygrob, 2020-02-27:
Hi!

I added the touchscreen connector for the new screen: DF37NB-10DS-0.4V.
The rest is the same!

exploshot, 2020-02-27:
Thank you for your fast answer :)

d3mon187, 2020-02-27:
If you're using the original smarchwatch bom, make sure you purchase the correct 0.39 ohm resistor.  The part number listed in the doc is for a 390 ohm resistor.

dannygrob, 2020-02-28:
I'll post an updated BOM

Closed 2020-02-27.

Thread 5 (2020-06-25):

It is possible to add more sensors?

omnibus12, 2020-06-25:
I wonder if it is possible to add more sensors if yes, where and how to program them.

dannygrob, 2020-06-27:
Hi,

Yes it's open and de ic has many more inputs. You can add whatever you like. There is no way for me to tell you how to program them, as this depends on what to add. I suggest looking over the schematic and code to get a sense of how it works to handle the accelerometer for example. It is not easy!

Danny

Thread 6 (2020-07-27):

Android and NFC?

boelle, 2020-07-27:
would those 2 be possible so it can be used to pay in stores?

d3mon187, 2020-07-27:
The SoC is very basic and doesn't support running Android, but I did get notifications working with Android phones.  On the plus side, the SoC is very basic and can theoretically run a long time on a battery doing basic smart watch Bluetooth functions.  NFC is probably possible to add, but I have a feeling it would be a huge task and tons of programming and I that's ignoring the idea of supporting credit card transactions.  I know I, and Danny too I'm sure, want to eventually get this project to a more usable state, but currently just telling time reliably and cleanly is a thing that still needs work.  If you are a good programmer, it is a challenging and rewarding project, but I feel like people should go into it with realistic expectations.  That said, I'm happy to help anyone else who would like to attempt it and contribute to the project.

boelle, 2020-07-27:
sadly not a programmer by any means, so its more an idea or a wish

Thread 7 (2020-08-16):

starter guide

eswarkeshav2001, 2020-08-16:
Sir, I know a bit about electronics and I almost totally figured how to make my own smartwatch circuit. I trying to add a heart rate sensor on my setup (i.e created by referring ur setup has reference).but I have no idea how to flash the program to the controller, and on which language I should write the code, (is it like Arduino or esp32). I checked on samsonmarch's thread there was a lot of code file. how I could merge that and flash it on my controller.please guide me through this whole process from scratch.or please make a guide that will very helpful to all of us and it will help this project to reach a lot of electronics enthusiasts.

dannygrob, 2020-08-16:
Adding a heartrate sensor would not be hard. I would not advice going on this route, as the DialogSemi is not easy to get started with and super limited in performance. The platform is just not really user friendly.
I wrote a [Getting started guide](https://github.com/dannygrob/OpenWatch/blob/master/OpenWatch%20getting%20started%20guide%5Bwip%5D.pdf) guid and is a good place to get everything running, but I can't guide more than this.

eswarkeshav2001, 2020-08-16:
Thanks a lot sir for your quick response.And i have small request sir. Can
you please refer a microcontroller with ble function which will be user
friendly.That would help me a lot sir

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

dannygrob, 2020-08-16:
I was looking at STM32F4 which seems more suitable for wearables. They have a better ecosystem and are better equipped to do graphics. However, designing a pcb for this is hard, as they don't have BLE integrated but require a separate ic. Maybe a STM32WB with the same LCD as this project uses.

For more entry level go for a ESP32 and basic OLED display to get started! Get a WROOM32 module and a 128x128 oled to get started with something very managable. Adding heartrate is easy on that platform, and there is a lot of documentation everywhere.

I want to get this project transferred to STM at some point, but even for me this is a huge step.

eswarkeshav2001, 2020-08-16:
Thank you for your guidance sir. Sir first let me introduce myself, sir. I
am Eswar reddy. I am studying 3rd-year B.Tech(Electrical and Electronics)
in the Vellore institute of technology in India. You might not know it but
it is one of the good institutes in India. I wanted to make a health care
wearable as my capstone project. And I have done some projects with ESP-32,
ESP-8266, and Arduino. I have done a project  called Smart plant pot at my
first year of b.tech Which senses a soil moisture level and the water level
in the pot. That is used to pour water to plant that is planted on the pot
and pour water to the soil using a water pump that is inbuilt on the pot if
moisture decreases below a certain level and the user can go through all of
these through an IoT platform called cayenne.in this project also I used
Esp-32. ok sir I don't wanna bore you with the stuffs I did.you greatly
rebuild the watch sir. that is really an amazing work.i will try to upgrade
this watch with my knowledge sir. And if you have time please go through my
smart plant pot presentation i attached the link for the for my
presentation below. And I would feel very good if u go through it sir
Please give me your Linkedin id sir.so I could follow on Linkedin and
please accept my follow request. And once  again thank you for your time
and guidance  sir

  Smart plant pot.pptx
<https://drive.google.com/file/d/1EOssqp6siu-d_2lXqGembedn0gMN45eD/view?usp=drivesdk>

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

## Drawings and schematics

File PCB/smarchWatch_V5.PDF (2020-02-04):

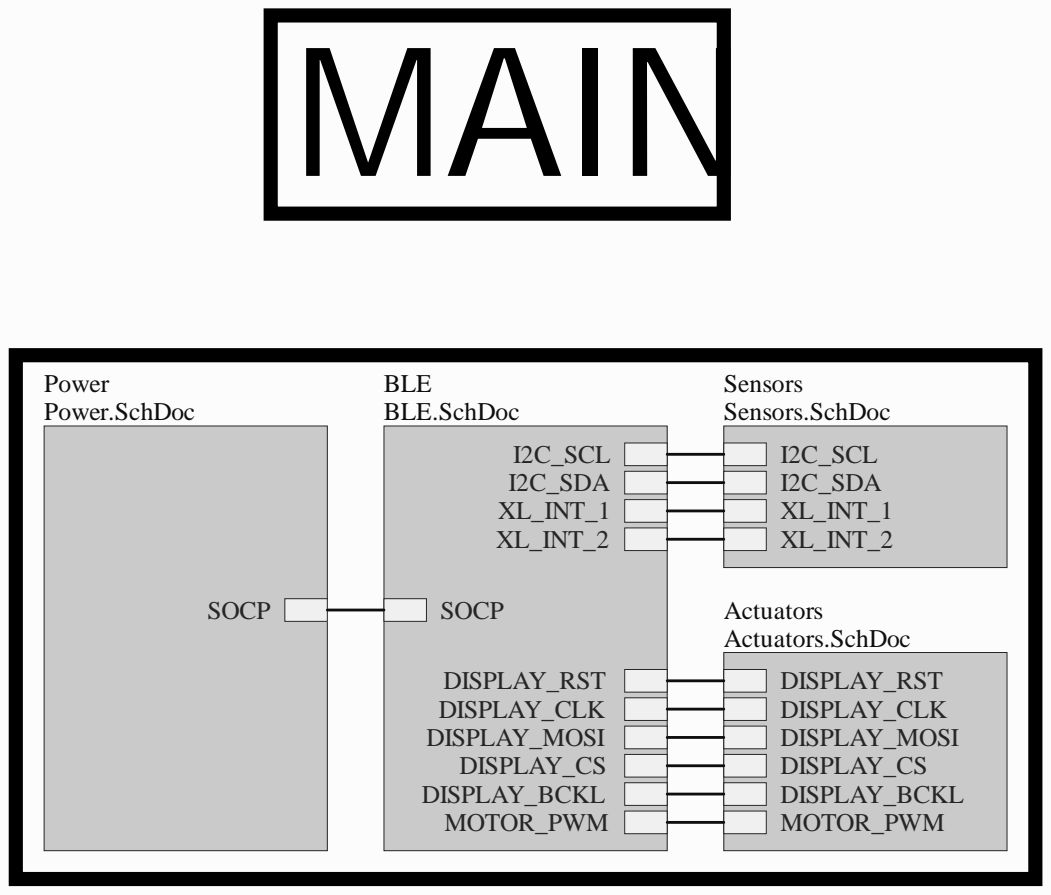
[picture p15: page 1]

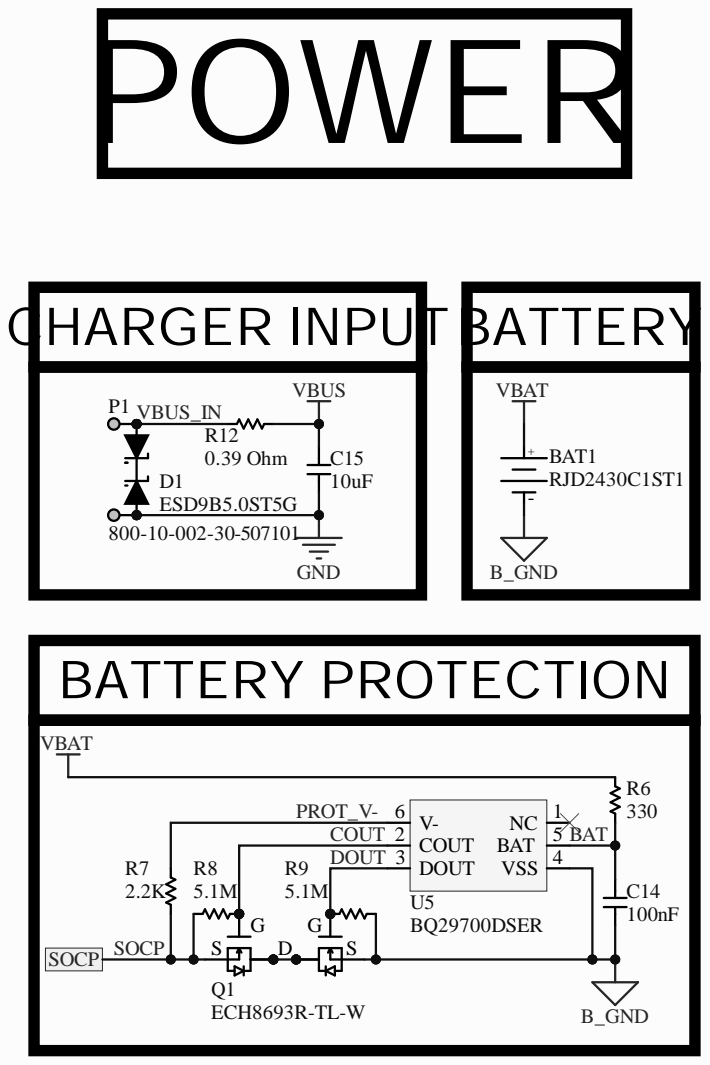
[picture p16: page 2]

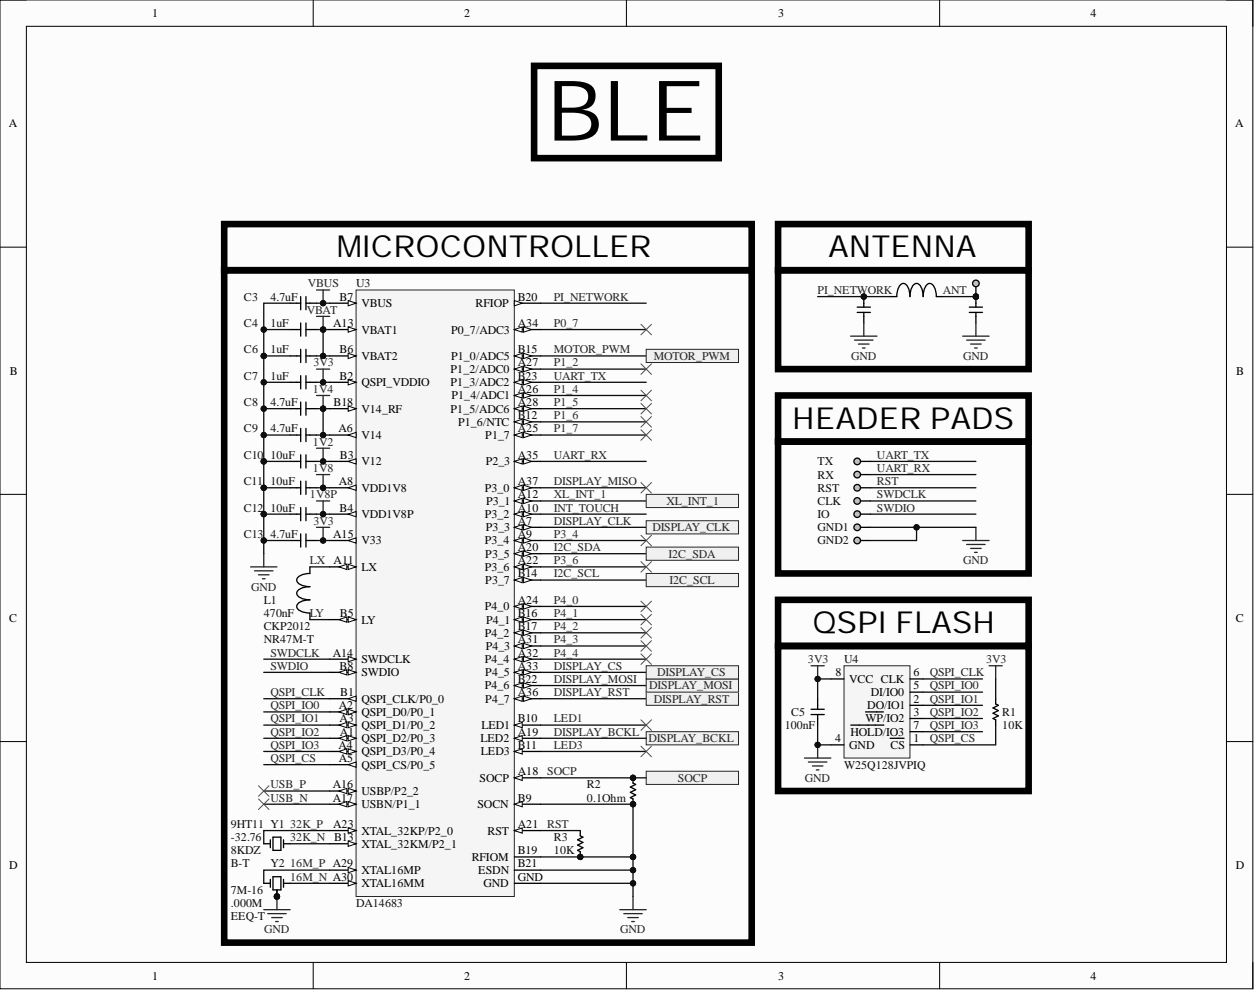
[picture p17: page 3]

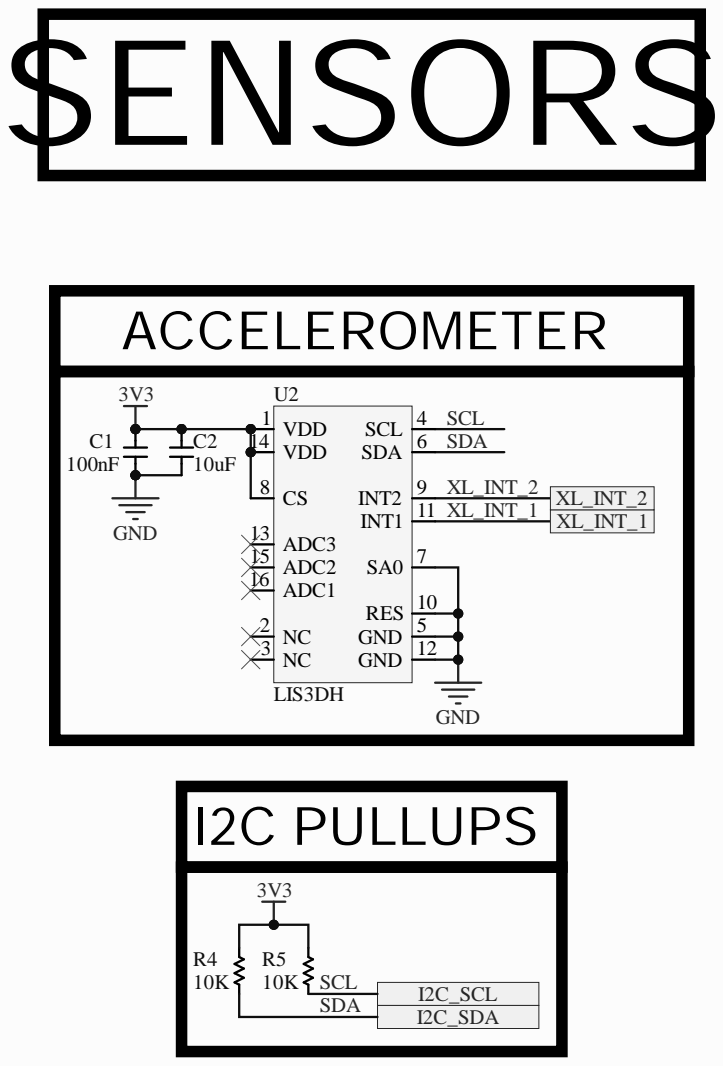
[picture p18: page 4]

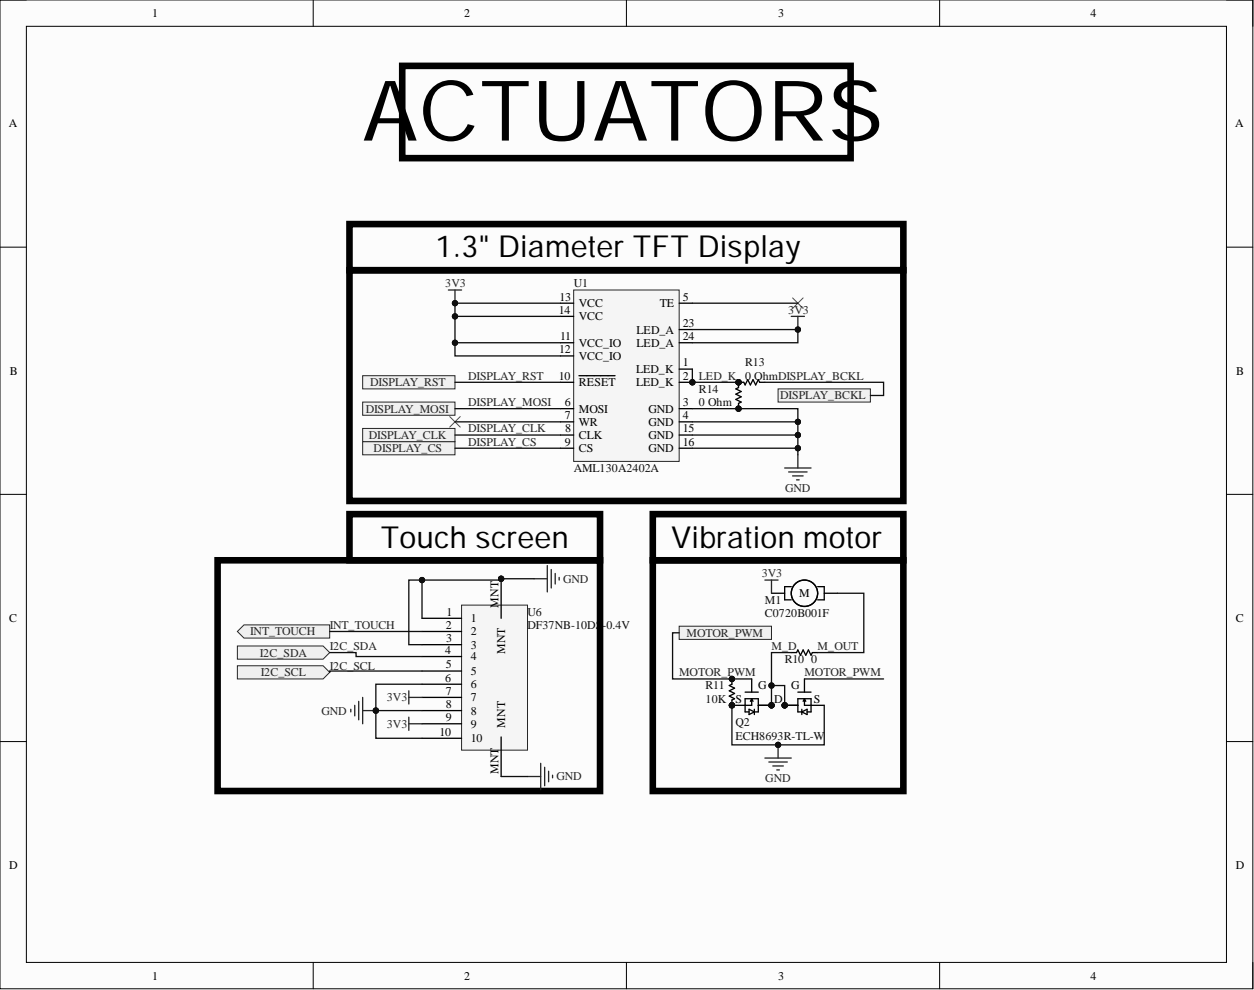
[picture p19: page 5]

MNT MNT

7 7
8 8
9 9

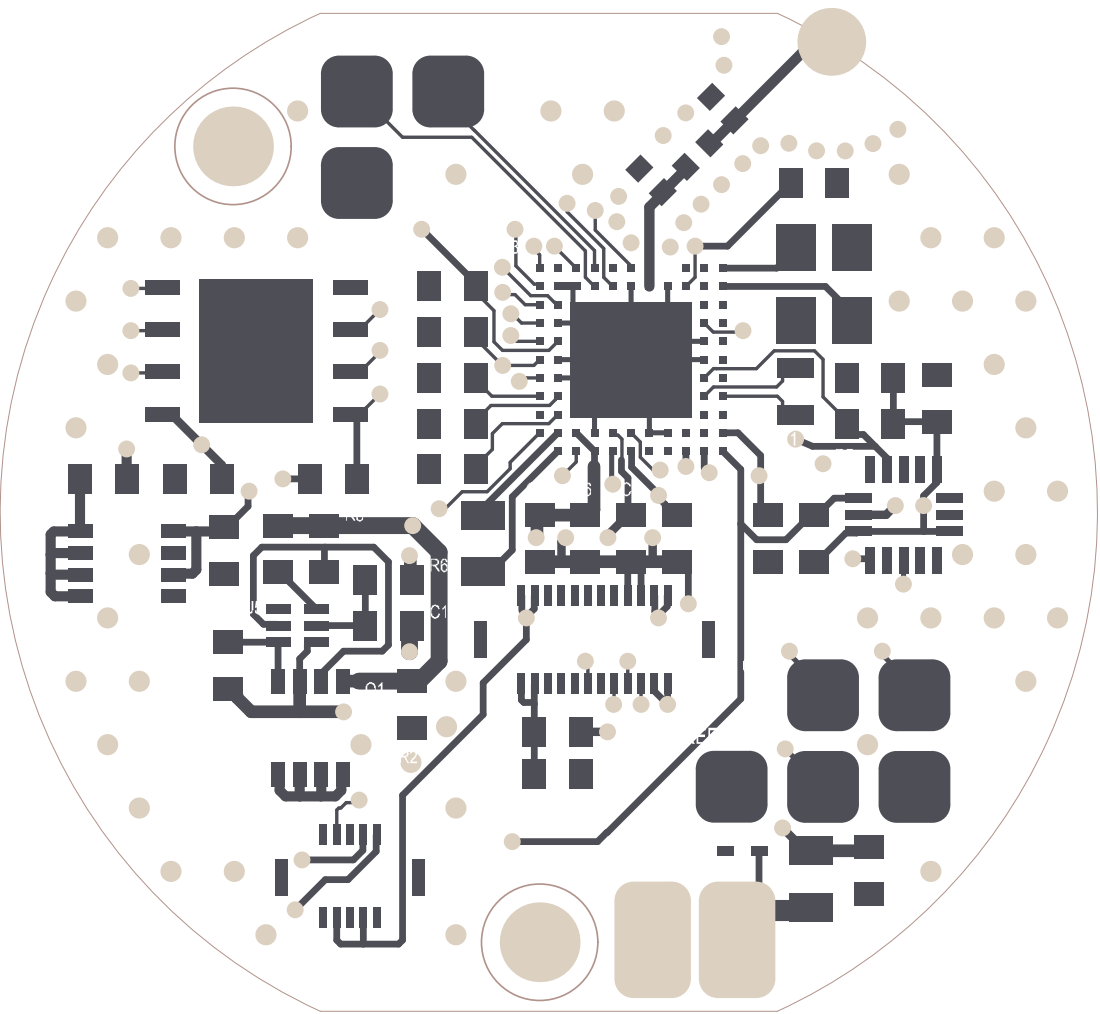
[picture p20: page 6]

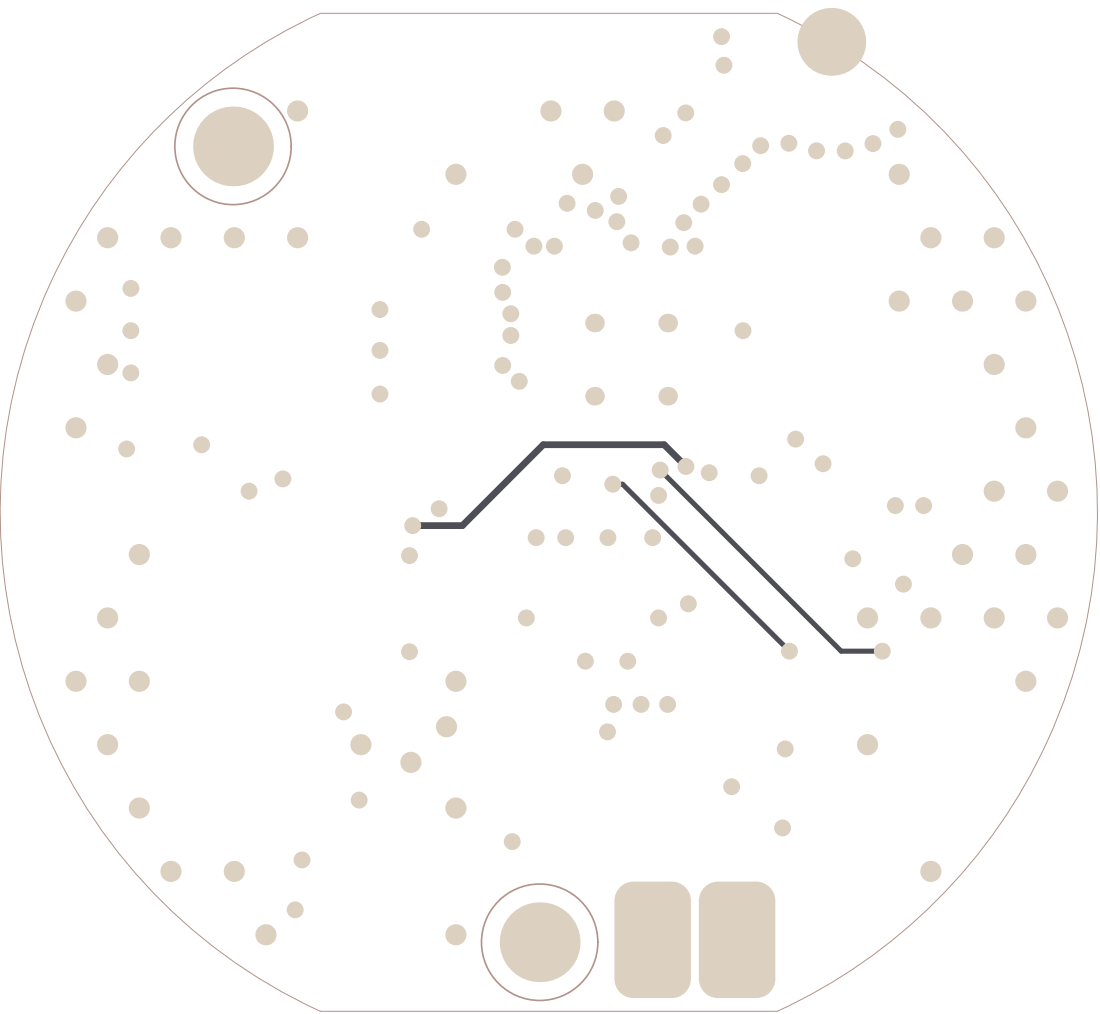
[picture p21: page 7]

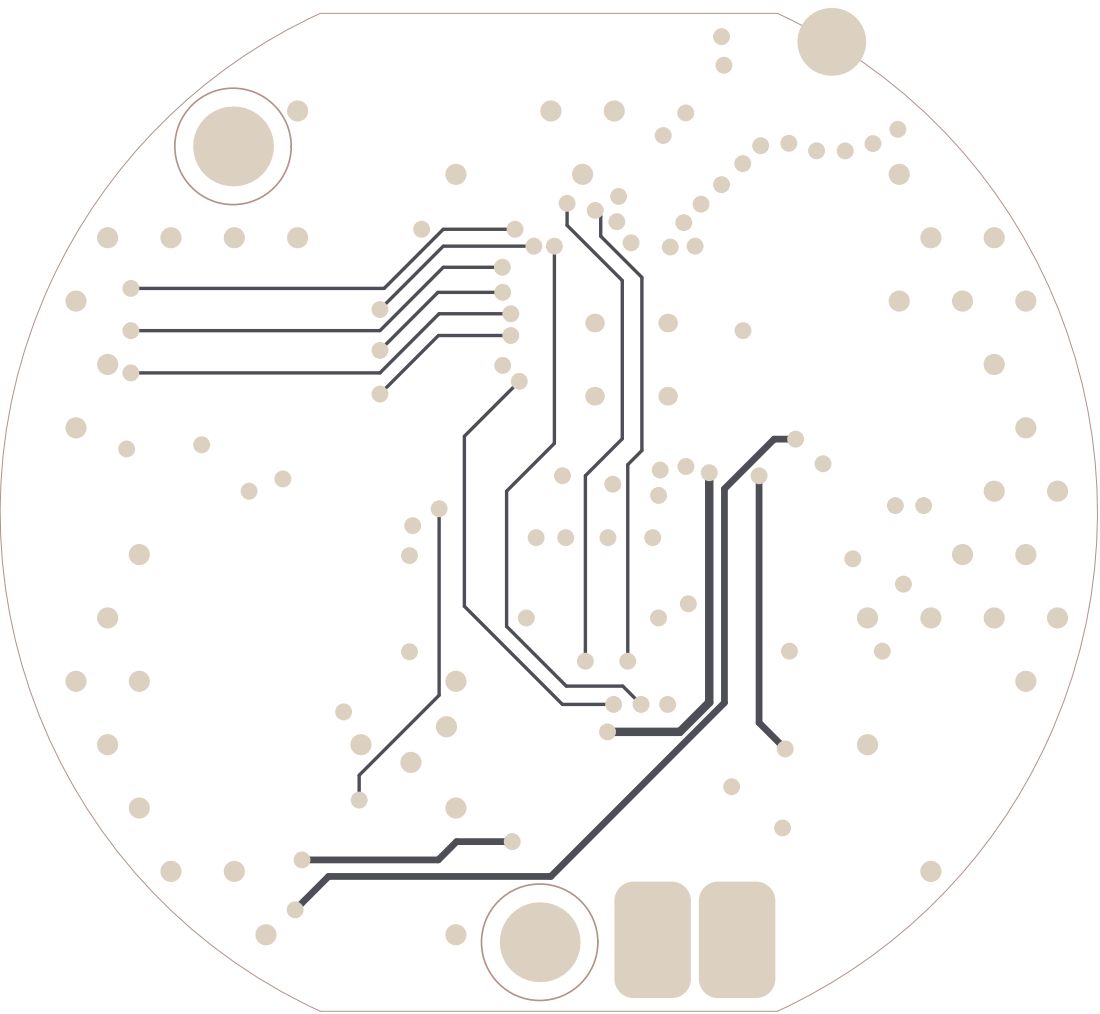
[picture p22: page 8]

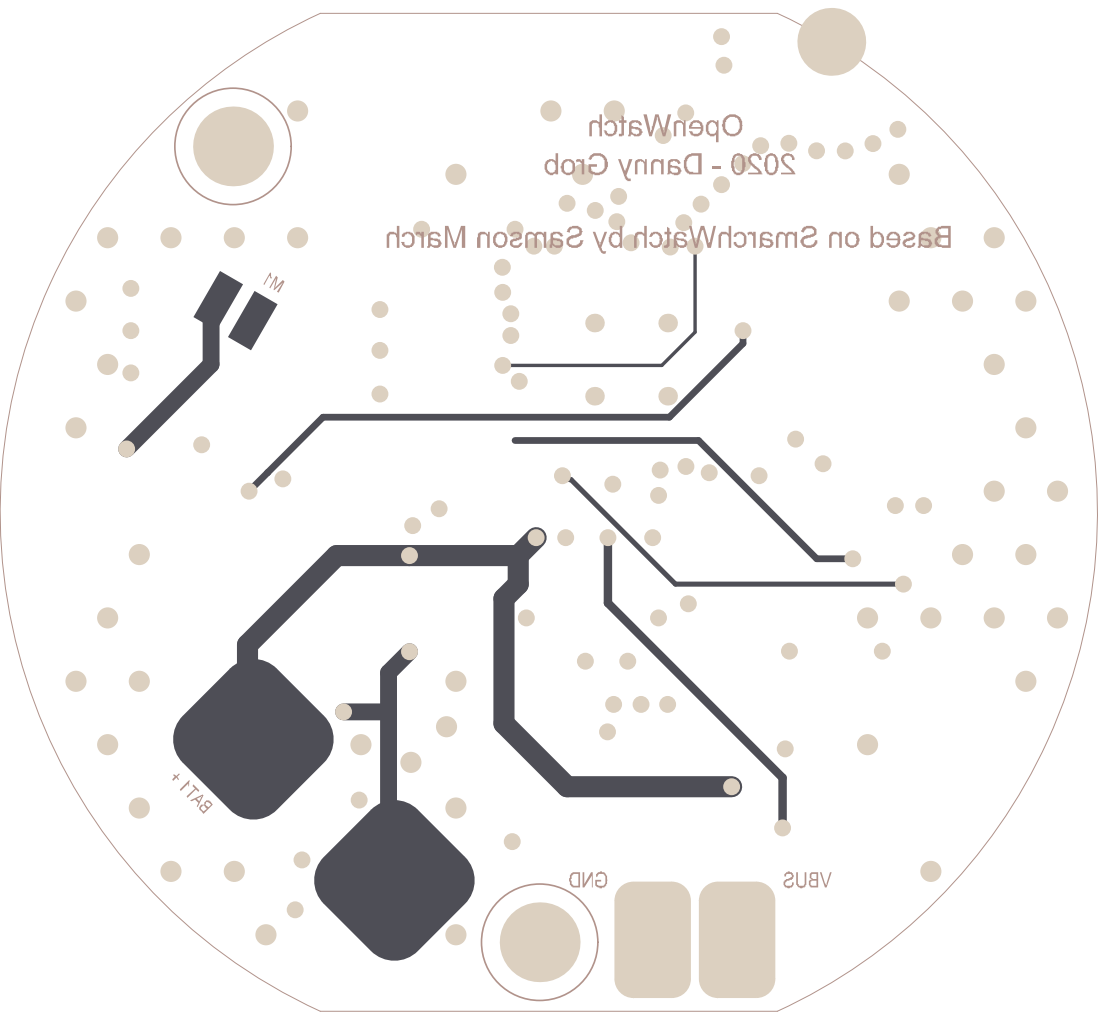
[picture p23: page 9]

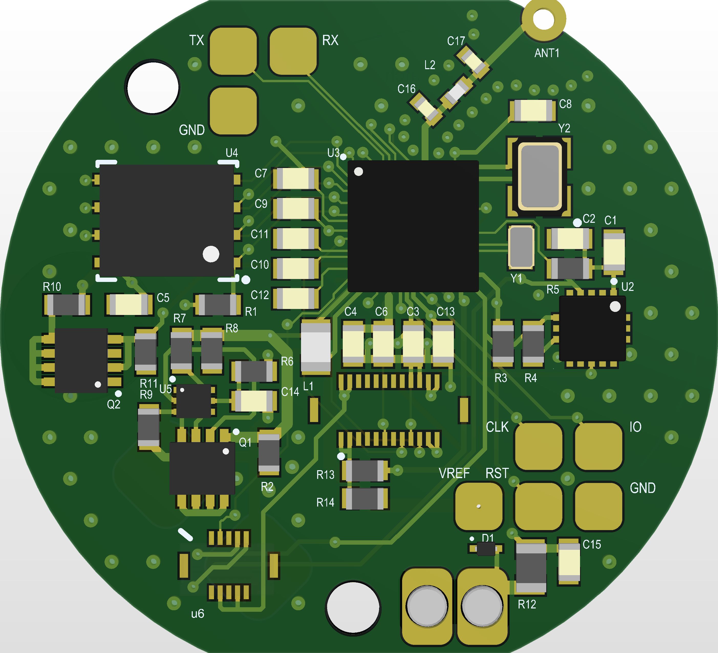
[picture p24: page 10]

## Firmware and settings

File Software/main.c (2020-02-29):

/**
 ****************************************************************************************
 *
 * @file main.c
 *
 * @brief ANCS application
 *
 * Copyright (C) 2015-2018 Dialog Semiconductor.
 * This computer program includes Confidential, Proprietary Information
 * of Dialog Semiconductor. All Rights Reserved.
 *
 ****************************************************************************************
 */
/* Standard includes. */
#include <string.h>
#include <stdbool.h>

#include "osal.h"
#include "resmgmt.h"
#include "ad_ble.h"
#include "ad_spi.h"
#include "ad_nvms.h"
#include "ble_mgr.h"
#include "hw_gpio.h"
#include "hw_wkup.h"
#include "hw_i2c.h"

#include "sys_clock_mgr.h"
#include "sys_power_mgr.h"
#include "sys_watchdog.h"
#include "ancs_config.h"
#include "platform_devices.h"


/* Task priorities */
#define mainBLE_ANCS_TASK_PRIORITY              ( OS_TASK_PRIORITY_NORMAL )
#define mainDISPLAY_TASK_PRIORITY               ( OS_TASK_PRIORITY_HIGHEST )
#define mainFLASH_TASK_PRIORITY                 ( OS_TASK_PRIORITY_NORMAL )
#define mainLIS3DH_TASK_PRIORITY                ( OS_TASK_PRIORITY_LOWEST )
#define mainTOUCH_TASK_PRIORITY                 ( OS_TASK_PRIORITY_NORMAL )

#define CFG_GPIO_I2C1_SCL_PORT          (HW_GPIO_PORT_3)
#define CFG_GPIO_I2C1_SCL_PIN           (HW_GPIO_PIN_7)
#define CFG_GPIO_I2C1_SDA_PORT          (HW_GPIO_PORT_3)
#define CFG_GPIO_I2C1_SDA_PIN           (HW_GPIO_PIN_5)

#if dg_configUSE_WDOG
INITIALISED_PRIVILEGED_DATA int8_t idle_task_wdog_id = -1;
#endif

/*
 * Perform any application specific hardware configuration.  The clocks,
 * memory, etc. are configured before main() is called.
 */
static void prvSetupHardware( void );
/*
 * Task functions .
 */

void ancs_task(void *params);
void display_task(void *params);
void lis3dh_task(void *params);
void touch_task(void *params);

static OS_TASK handle;
static OS_TASK handle1;
static OS_TASK handle2;
static OS_TASK handle3;
static OS_TASK handle4;
/*
 * Wakeup handler
 */
void ancs_client_wkup_handler(void);

static void wkup_handler()
{
#if dg_configBLACK_ORCA_IC_REV == BLACK_ORCA_IC_REV_A
        hw_wkup_reset_counter();
#endif
        hw_wkup_reset_interrupt();

        ancs_client_wkup_handler();
}

static void init_wakeup(void)
{
        hw_wkup_init(NULL);
        hw_wkup_configure_pin(CFG_TRIGGER_PERFORM_NOTIF_ACTION_GPIO_PORT,
                                                        CFG_TRIGGER_PERFORM_NOTIF_ACTION_GPIO_PIN, 1,
                                                        HW_WKUP_PIN_STATE_LOW);
#if dg_configBLACK_ORCA_IC_REV == BLACK_ORCA_IC_REV_A
        hw_wkup_set_counter_threshold(1);
#endif
        hw_wkup_set_debounce_time(10);

        hw_wkup_register_interrupt(wkup_handler, 1);
}

/**n
 * @brief System Initialization and creation of the BLE task
 */
static void system_init( void *pvParameters )
{
#if defined CONFIG_RETARGET
        extern void retarget_init(void);
#endif

        /* Prepare clocks. Note: cm_cpu_clk_set() and cm_sys_clk_set() can be called only from a
         * task since they will suspend the task until the XTAL16M has settled and, maybe, the PLL
         * is locked.
         */
        //cm_sys_clk_init(sysclk_PLL96);
        cm_sys_clk_init(sysclk_XTAL16M);
        cm_apb_set_clock_divider(apb_div1);
        cm_ahb_set_clock_divider(ahb_div1);
        cm_lp_clk_init();

        /*
         * Initialize platform watchdog
         */
        sys_watchdog_init();

#if dg_configUSE_WDOG
        // Register the Idle task first.
        idle_task_wdog_id = sys_watchdog_register(false);
        ASSERT_WARNING(idle_task_wdog_id != -1);
        sys_watchdog_configure_idle_id(idle_task_wdog_id);
#endif

        /* Set system clock */
        cm_sys_clk_set(sysclk_PLL96);
       // cm_sys_clk_set(sysclk_PLL96);

        /* Prepare the hardware to run this demo. */
        prvSetupHardware();

        /* init resources */
        resource_init();

#if defined CONFIG_RTT
        SEGGER_RTT_Init();
#endif


#if defined CONFIG_RETARGET
        retarget_init();
#endif

        /* Initialize wakeup GPIO pins used in demo */
        init_wakeup();

        initTimeClient();

        /* Set the desired sleep mode. */
        pm_set_wakeup_mode(true);
        ad_i2c_init();

        pm_set_sleep_mode(pm_mode_active);
      //  pm_set_sleep_mode(pm_mode_extended_sleep);
        /* Initialize BLE Manager */
        ble_mgr_init();
//        sprintf("%s", "test");
        /* Start the Display application task. */
        OS_TASK_CREATE("Display Task",                     /* The text name assigned to the task, for
                                                              debug only; not used by the kernel. */
                       display_task,                          /* The function that implements the task. */
                       NULL,                               /* The parameter passed to the task. */
                       4096,                               /* The number of bytes to allocate to the
                                                              stack of the task. */
                       mainDISPLAY_TASK_PRIORITY,         /* The priority assigned to the task. */
                       handle1);                            /* The task handle. */
        OS_ASSERT(handle1);
#ifndef DEVKIT_USB
        /* Start the LIS3DH application task. */
        OS_TASK_CREATE("LIS3DH Task",                     /* The text name assigned to the task, for
                                                              debug only; not used by the kernel. */
                       lis3dh_task,                          /* The function that implements the task. */
                       NULL,                               /* The parameter passed to the task. */
                       1024,                               /* The number of bytes to allocate to the
                                                              stack of the task. */
                       mainLIS3DH_TASK_PRIORITY,         /* The priority assigned to the task. */
                       handle2);                            /* The task handle. */
        OS_ASSERT(handle2);
#endif
//        /* Start the Touch application task. */
//        OS_TASK_CREATE("Touch Task",                     /* The text name assigned to the task, for                                                              debug only; not used by the kernel. */
//                       touch_task,                          /* The function that implements the task. */
//                       NULL,                               /* The parameter passed to the task. */
//                       1024,                               /* The number of bytes to allocate to the
//                                                              stack of the task. */
//                       mainTOUCH_TASK_PRIORITY,         /* The priority assigned to the task. */
//                       handle4);                            /* The task handle. */
//        OS_ASSERT(handle4);

        /* Start the ANCS Profile application task. */
        OS_TASK_CREATE("ANCS Profile",                     /* The text name assigned to the task, for
                                                              debug only; not used by the kernel. */
                       ancs_task,                          /* The function that implements the task. */
                       NULL,                               /* The parameter passed to the task. */
                       1024,                               /* The number of bytes to allocate to the
                                                              stack of the task. */
                       mainBLE_ANCS_TASK_PRIORITY,         /* The priority assigned to the task. */
                       handle3);                            /* The task handle. */
        OS_ASSERT(handle3);


        /* the work of the SysInit task is done */
        OS_TASK_DELETE(OS_GET_CURRENT_TASK());


}
/*-----------------------------------------------------------*/

/**
 * @brief Basic initialization and creation of the system initialization task.
 */
int main( void )
{
        OS_BASE_TYPE status;
        cm_clk_init_low_level();                            /* Basic clock initializations. */

        /* Start SysInit task. */
        status = OS_TASK_CREATE("SysInit",                /* The text name assigned to the task, for
                                                             debug only; not used by the kernel. */
                                system_init,              /* The System Initialization task. */
                                ( void * ) 0,             /* The parameter passed to the task. */
                                1024,                     /* The number of bytes to allocate to the
                                                             stack of the task. */
                                OS_TASK_PRIORITY_HIGHEST, /* The priority assigned to the task. */
                                handle );                 /* The task handle */
        OS_ASSERT(status == OS_TASK_CREATE_SUCCESS);

        /* Start the tasks and timer running. */
        vTaskStartScheduler();

        /* If all is well, the scheduler will now be running, and the following
        line will never be reached.  If the following line does execute, then
        there was insufficient FreeRTOS heap memory available for the idle and/or
        timer tasks     to be created.  See the memory management section on the
        FreeRTOS web site for more details. */
        for( ;; );
}

/**
 * \brief Initialize the peripherals domain after power-up.
 *
 */

static void periph_init(void)
{
        //UART
        hw_gpio_set_pin_function(HW_GPIO_PORT_1, HW_GPIO_PIN_3, HW_GPIO_MODE_OUTPUT,
                HW_GPIO_FUNC_UART2_TX);
        hw_gpio_set_pin_function(HW_GPIO_PORT_2, HW_GPIO_PIN_3, HW_GPIO_MODE_OUTPUT,
                HW_GPIO_FUNC_UART2_RX);

        //SPI
        hw_gpio_set_pin_function(HW_GPIO_PORT_3, HW_GPIO_PIN_3, HW_GPIO_MODE_OUTPUT,
                HW_GPIO_FUNC_SPI_CLK);
        hw_gpio_set_pin_function(HW_GPIO_PORT_3, HW_GPIO_PIN_0, HW_GPIO_MODE_INPUT,
                HW_GPIO_FUNC_SPI_DI);
        hw_gpio_set_pin_function(HW_GPIO_PORT_4, HW_GPIO_PIN_6, HW_GPIO_MODE_OUTPUT,
                HW_GPIO_FUNC_SPI_DO);
        hw_gpio_set_pin_function(HW_GPIO_PORT_4, HW_GPIO_PIN_5, HW_GPIO_MODE_OUTPUT,
                HW_GPIO_FUNC_SPI_EN);
        hw_gpio_set_active(HW_GPIO_PORT_4,HW_GPIO_PIN_5);

        //Display Reset
        hw_gpio_set_pin_function(HW_GPIO_PORT_4, HW_GPIO_PIN_7, HW_GPIO_MODE_OUTPUT, HW_GPIO_FUNC_GPIO);
        hw_gpio_set_active(HW_GPIO_PORT_4,HW_GPIO_PIN_7);

        //Vibration
        hw_gpio_set_pin_function(HW_GPIO_PORT_1, HW_GPIO_PIN_0, HW_GPIO_MODE_OUTPUT, HW_GPIO_FUNC_GPIO);


        //BLE TURN DOWN CALL
        hw_gpio_configure_pin(CFG_TRIGGER_PERFORM_NOTIF_ACTION_GPIO_PORT,
                        CFG_TRIGGER_PERFORM_NOTIF_ACTION_GPIO_PIN, HW_GPIO_MODE_INPUT_PULLUP,
                        HW_GPIO_FUNC_GPIO, 1);

        //-----I2C port/pin config ------P3.7=SCL, P3.5=SDA--------
        hw_gpio_configure_pin(CFG_GPIO_I2C1_SCL_PORT,CFG_GPIO_I2C1_SCL_PIN, HW_GPIO_MODE_OUTPUT, HW_GPIO_FUNC_I2C_SCL,false);
        hw_gpio_configure_pin(CFG_GPIO_I2C1_SDA_PORT,CFG_GPIO_I2C1_SDA_PIN, HW_GPIO_MODE_INPUT, HW_GPIO_FUNC_I2C_SDA,false);

#ifdef DEVKIT_USB
        hw_gpio_configure_pin(HW_GPIO_PORT_3, HW_GPIO_PIN_1, HW_GPIO_MODE_INPUT_PULLUP, HW_GPIO_FUNC_GPIO, true);
        hw_gpio_configure_pin(HW_GPIO_PORT_1, HW_GPIO_PIN_4, HW_GPIO_MODE_INPUT_PULLDOWN, HW_GPIO_FUNC_GPIO, true);
        //led
        hw_gpio_set_pin_function(HW_GPIO_PORT_1,HW_GPIO_PIN_2, HW_GPIO_MODE_OUTPUT, HW_GPIO_FUNC_GPIO);
#else
        hw_gpio_configure_pin(HW_GPIO_PORT_3, HW_GPIO_PIN_1, HW_GPIO_MODE_INPUT_PULLDOWN, HW_GPIO_FUNC_GPIO, true);
        hw_gpio_configure_pin(HW_GPIO_PORT_3, HW_GPIO_PIN_2, HW_GPIO_MODE_INPUT_PULLDOWN, HW_GPIO_FUNC_GPIO, true);

#endif

}

static void prvSetupHardware( void )
{
        /* Init hardware */
        pm_system_init(periph_init);
}

/**
 * @brief Malloc fail hook
 */
void vApplicationMallocFailedHook( void )
{
        /* vApplicationMallocFailedHook() will only be called if
	configUSE_MALLOC_FAILED_HOOK is set to 1 in FreeRTOSConfig.h.  It is a hook
	function that will get called if a call to pvPortMalloc() fails.
	pvPortMalloc() is called internally by the kernel whenever a task, queue,
	timer or semaphore is created.  It is also called by various parts of the
	demo application.  If heap_1.c or heap_2.c are used, then the size of the
	heap available to pvPortMalloc() is defined by configTOTAL_HEAP_SIZE in
	FreeRTOSConfig.h, and the xPortGetFreeHeapSize() API function can be used
	to query the size of free heap space that remains (although it does not
	provide information on how the remaining heap might be fragmented). */
        taskDISABLE_INTERRUPTS();
        for( ;; );
}

/**
 * @brief Application idle task hook
 */
void vApplicationIdleHook( void )
{
        /* vApplicationIdleHook() will only be called if configUSE_IDLE_HOOK is set
           to 1 in FreeRTOSConfig.h.  It will be called on each iteration of the idle
           task. It is essential that code added to this hook function never attempts
           to block in any way (for example, call xQueueReceive() with a block time
           specified, or call vTaskDelay()).  If the application makes use of the
           vTaskDelete() API function (as this demo application does) then it is also
           important that vApplicationIdleHook() is permitted to return to its calling
           function, because it is the responsibility of the idle task to clean up
           memory allocated by the kernel to any task that has since been deleted. */

#if dg_configUSE_WDOG
        sys_watchdog_notify(idle_task_wdog_id);
#endif
}

/**
 * @brief Application stack overflow hook
 */
void vApplicationStackOverflowHook( OS_TASK pxTask, char *pcTaskName )
{
        ( void ) pcTaskName;
        ( void ) pxTask;

        /* Run time stack overflow checking is performed if
	configCHECK_FOR_STACK_OVERFLOW is defined to 1 or 2.  This hook
	function is called if a stack overflow is detected. */
        taskDISABLE_INTERRUPTS();
        for( ;; );
}

/**
 * @brief Application tick hook
 */
void vApplicationTickHook( void )
{

        OS_POISON_AREA_CHECK( OS_POISON_ON_ERROR_HALT, result );

}

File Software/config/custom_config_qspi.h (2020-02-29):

/**
\addtogroup BSP
\{
\addtogroup CONFIG
\{
\addtogroup CUSTOM
\{
*/

/**
 ****************************************************************************************
 *
 * @file custom_config_qspi.h
 *
 * @brief Board Support Package. User Configuration file for cached QSPI mode.
 *
 * Copyright (C) 2015-2017 Dialog Semiconductor.
 * This computer program includes Confidential, Proprietary Information
 * of Dialog Semiconductor. All Rights Reserved.
 *
 ****************************************************************************************
 */

#ifndef CUSTOM_CONFIG_QSPI_H_
#define CUSTOM_CONFIG_QSPI_H_

#include "bsp_definitions.h"

#define CONFIG_USE_BLE
#undef CONFIG_USE_FTDF

#define CONFIG_BLE_STORAGE (1)

//#define DEVKIT_USB                              (1)
//#define CONFIG_RETARGET                         (1)
//#define CONFIG_RETARGET_UART    HW_UART2

#define CONFIG_RTT

#define dg_configTESTMODE_MEASURE_SLEEP_CURRENT (0)

#define dg_configUSE_LP_CLK                     LP_CLK_32768
#define dg_configEXEC_MODE                      MODE_IS_CACHED
#define dg_configCODE_LOCATION                  NON_VOLATILE_IS_FLASH
#define dg_configEXT_CRYSTAL_FREQ               EXT_CRYSTAL_IS_16M

#define dg_configIMAGE_SETUP                    DEVELOPMENT_MODE
#define dg_configEMULATE_OTP_COPY               (0)

#define dg_configUSER_CAN_USE_TIMER1            (0)
#define dg_configUSE_HW_TIMER2                  (1)

#define CONFIG_LIS3DH                           (1)
#define CONFIG_IT7257                           (1)

#define dg_configUSE_WDOG                       (1)
#define dg_configI2C_ADAPTER                    (1)
#define dg_configUSE_HW_I2C                     (1)

#define dg_configFLASH_CONNECTED_TO             (FLASH_CONNECTED_TO_1V8)
#define dg_configFLASH_POWER_DOWN               (0)

#define dg_configPOWER_1V8_ACTIVE               (1)
#define dg_configPOWER_1V8_SLEEP                (1)
//
#define dg_configBATTERY_TYPE                   (BATTERY_TYPE_LIMN2O4)
#define dg_configBATTERY_CHARGE_CURRENT         3       // 30mA
#define dg_configBATTERY_PRECHARGE_CURRENT      20      // 2.1mA
#define dg_configBATTERY_CHARGE_NTC             1       // disabled


//#define dg_configBATTERY_TYPE                   (BATTERY_TYPE_CUSTOM)
#define dg_configBATTERY_CHARGE_VOLTAGE         0x0A // 4.2V
#define dg_configBATTERY_TYPE_CUSTOM_ADC_VOLTAGE (3440)
#define dg_configBATTERY_LOW_LEVEL              (2496) // 3V
#define dg_configPRECHARGING_THRESHOLD          (2462) // 3.006V
#define dg_configCHARGING_THRESHOLD             (2498) // 3.05V
#define dg_configBATTERY_CHARGE_CURRENT         3 // 45mA (see lib/sdk/bsp/system/sys_man/sys_charger.c:115)
//#define dg_configBATTERY_PRECHARGE_CURRENT      1 // 15mA
#define dg_configBATTERY_CHARGE_NTC             1 // disabled

#define dg_configPRECHARGING_TIMEOUT            (60 * 60 * 100) // N x 10msec
#define dg_configUSE_USB                        0
#define dg_configUSE_USB_CHARGER                1//MUST SET TO 1
#define dg_configUSE_USB_ENUMERATION            0
#define dg_configALLOW_CHARGING_NOT_ENUM        1
//
#define dg_configCHARGING_CC_TIMEOUT (360 * 60 * 100)
#define dg_configCHARGING_CV_TIMEOUT (720 * 60 * 100)
#define dg_configUSB_CHARGER_POLLING_INTERVAL (60 * 100) // 1 min (Unit: 0.01s)
#define dg_configBATTERY_REPLENISH_GAP (8) // 0.01V

#define dg_configUSE_ProDK                      (1)

#define dg_configUSE_SW_CURSOR                  0//(1)

#define dg_configCACHEABLE_QSPI_AREA_LEN        0x80000//(NVMS_PARAM_PART_start - MEMORY_QSPIF_BASE)
#define dg_configQSPI_CODE_SIZE                 (256 * 1024)

/*************************************************************************************************\
 * Custom flash specific config
 */
#define dg_configFLASH_HEADER_FILE              "qspi_w25q128.h"
#define dg_configFLASH_DEVICE_TYPE              W25Q128
#define dg_configFLASH_DENSITY                  W25Q_128Mb_SIZE
#define USE_PARTITION_TABLE_16MB


/*************************************************************************************************\
 * Memory layout specific config
 */
#define dg_configQSPI_CACHED_RAM_SIZE           ( 56 * 1024)
#define dg_configQSPI_CACHED_RETRAM_0_SIZE      ( 72 * 1024)//72*1024

/*************************************************************************************************\
 * FreeRTOS specific config
 */
#define OS_FREERTOS                              /* Define this to use FreeRTOS */
#define configTOTAL_HEAP_SIZE                    (19 * 1024)//19*1024//19456   /* This is the FreeRTOS Total Heap Size */
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

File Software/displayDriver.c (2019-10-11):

/*
 * displayDriver.c
 *
 *  Created on: Jan 15, 2019
 *      Author: samsonm
 */

#include <stdint.h>
#include "math.h"
#include "displayDriver.h"
#include "platform_devices.h"
#include "ad_spi.h"
#include "ad_nvms.h"
#include "miniDB.h"
#include "hw_led.h"
#include "hw_timer2.h"
#include "sys_power_mgr.h"
#include <hw_breath.h>

//#define STORAGE_PART NVMS_GENERIC_PART
#define STORAGE_PART  NVMS_FLASH_STORAGE

PRIVILEGED_DATA static OS_TIMER buzz_timer;

int buzz_milliseconds = 0;

spi_device displaySpi;

uint8_t commonWriteBuffer[SPI_WRITE_BUFFER_SIZE] = {0};
bool devIsOpen = false;

int absoluteValue(int NUMBER)
{
    if(NUMBER<0)
    {
        return -NUMBER;
    }
    else
    {
        return NUMBER;
    }
}

int deviceIsOpen() {
        return devIsOpen;
}
void openDevice() {
#ifdef CONFIG_SPI_DISPLAY
        if (devIsOpen == true) {
                return;
        }
        displaySpi = ad_spi_open(DISPLAY_SPI);
        devIsOpen=true;
#endif
}
void closeDevice() {
#ifdef CONFIG_SPI_DISPLAY
        if (devIsOpen == false) {
                return;
        }
        ad_spi_close(displaySpi);
        devIsOpen=false;
#endif
}

int bitIsSetTo = -1;

void displayWriteCommand(int COMMAND)
{
#ifdef CONFIG_SPI_DISPLAY
        if (devIsOpen == false) {
                displaySpi = ad_spi_open(DISPLAY_SPI);
        }

        hw_spi_set_9th_bit(ad_spi_get_hw_spi_id(displaySpi),0);

        ad_spi_write(displaySpi,(uint8_t *)&COMMAND,1);
        if (devIsOpen == false) {
                ad_spi_close(displaySpi);
        }
#endif
}
void displayWriteData(int DATA)
{
#ifdef CONFIG_SPI_DISPLAY

        if (devIsOpen == false) {
                displaySpi = ad_spi_open(DISPLAY_SPI);
        }
        hw_spi_set_9th_bit(ad_spi_get_hw_spi_id(displaySpi),1);

        ad_spi_write(displaySpi,(uint8_t *)&DATA,1);
        if (devIsOpen == false) {
                ad_spi_close(displaySpi);
        }
#endif
}

void displayWriteDataBuf(uint8_t DATA[], int DATA_SIZE)
{
#ifdef CONFIG_SPI_DISPLAY
        if (devIsOpen == false) {
                displaySpi = ad_spi_open(DISPLAY_SPI);
        }
        hw_spi_set_9th_bit(ad_spi_get_hw_spi_id(displaySpi),1);

        ad_spi_write(displaySpi,DATA,DATA_SIZE);
        if (devIsOpen == false) {
                ad_spi_close(displaySpi);
        }
#endif
}
void displayInit2(void) {
#ifdef CONFIG_SPI_DISPLAY
        //Initial_ST7789V
        //Software Reset
        hw_gpio_set_active(HW_GPIO_PORT_4,HW_GPIO_PIN_7);
        OS_DELAY_MS(120);
        hw_gpio_set_inactive(HW_GPIO_PORT_4, HW_GPIO_PIN_7);
        OS_DELAY_MS(120);
        hw_gpio_set_active(HW_GPIO_PORT_4,HW_GPIO_PIN_7);
        OS_DELAY_MS(120);

        displayWriteCommand(0x01);
        OS_DELAY_MS(10);
        displayWriteCommand(0x11);

        OS_DELAY_MS(10);

        displayWriteCommand(0x36);
        displayWriteData(0x00);

        displayWriteCommand(ST7789_COLMOD);
        displayWriteData(0x55);
        //displayWriteCommand(0x3A);
        //displayWriteData(0x06);

        displayWriteCommand(0xB2);
        displayWriteData(0x0C);
        displayWriteData(0x0C);
        displayWriteData(0x00);
        displayWriteData(0x33);
        displayWriteData(0x33);

        displayWriteCommand(0xB7);
        displayWriteData(0x75);

        displayWriteCommand(0xBB);
        displayWriteData(0x3D);   //Vcom=1.625V

        displayWriteCommand(0xC2);
        displayWriteData(0x01);

        displayWriteCommand(0xC3);
        displayWriteData(0x19);   //GVDD=4.8V

        displayWriteCommand( 0xC4);
        displayWriteData(0x20);   //VDV, 0x20:0v

        displayWriteCommand(0xC6);
        //displayWriteData(0x0F);   //0x0F:60Hz
        displayWriteData(0x01);   //0x01:111Hz

        displayWriteCommand(0xD0);
        displayWriteData(0xA4);
        displayWriteData(0xA1);

        displayWriteCommand(0xD6);
        displayWriteData(0xA1);//sleep ingate

        displayWriteCommand(0xE0);
        displayWriteData(0x70);
        displayWriteData(0x04);
        displayWriteData(0x08);
        displayWriteData(0x09);
        displayWriteData(0x09);
        displayWriteData(0x05);
        displayWriteData(0x2A);
        displayWriteData(0x33);
        displayWriteData(0x41);
        displayWriteData(0x07);
        displayWriteData(0x13);
        displayWriteData(0x13);
        displayWriteData(0x29);
        displayWriteData(0x2F);
        displayWriteCommand(0xE1);
        displayWriteData(0x70);
        displayWriteData(0x03);
        displayWriteData(0x09);
        displayWriteData(0x0A);
        displayWriteData(0x09);
        displayWriteData(0x06);
        displayWriteData(0x2B);
        displayWriteData(0x34);
        displayWriteData(0x41);
        displayWriteData(0x07);
        displayWriteData(0x12);
        displayWriteData(0x14);
        displayWriteData(0x28);
        displayWriteData(0x2E);

        displayWriteCommand(0x21);

        displayWriteCommand(0x29);



        displayWriteCommand(0x2A);     //Column Address Set
        displayWriteData(0x00);
        displayWriteData(0x00);   //0
        displayWriteData(0x00);
        displayWriteData(0xEF);   //239

        displayWriteCommand(0x2B);     //Row Address Set
        displayWriteData(0x00);
        displayWriteData(0x00);   //0
        displayWriteData(0x00);
        displayWriteData(0xEF);   //239

        displayWriteCommand(0x2C);
#endif
}
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

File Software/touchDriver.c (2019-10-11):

#include <stdio.h>
#include <string.h>
#include <stdlib.h>
#include <time.h>
#include <osal.h>
#include <platform_devices.h>
#include <hw_i2c.h>
#include <resmgmt.h>
#include "it7257Registers.h"
#include "touchDriver.h"
#include "miniDB.h"

i2c_device dev;

typedef struct i2c_event
{
        OS_EVENT os_event;
        HW_I2C_ABORT_SOURCE error;
} i2c_event;

/*
 * Signaling event used in operation started from GUI task.
 */
static i2c_event i2c_signal;

/*
 * Initialize event structure used in this demo.
 */
static void init_event(i2c_event *event)
{
        event->error = 0;
        OS_EVENT_CREATE(event->os_event);
}

/*
 * Callback passed to i2c_async_transact. It signals event passed as user data.
 */
static void signal_event(void *user_data, HW_I2C_ABORT_SOURCE error)
{
        i2c_event *event = (i2c_event *) user_data;
        event->error = error;
        OS_EVENT_SIGNAL_FROM_ISR(event->os_event);
}

/*
 * Resets event used for synchronization.
 */
static void reset_event(i2c_event *event)
{
        event->error = 0;
        OS_EVENT_WAIT(event->os_event, OS_EVENT_NO_WAIT);
}

/*
 * Wait for event to be in signaled state.
 */
static void wait_for_event(i2c_event *event)
{
        OS_EVENT_WAIT(event->os_event, OS_EVENT_FOREVER);
}

/*
 * Write sensor register
 */
static inline void write_reg_async(i2c_device dev, uint8_t reg, const uint8_t *val,
                                                uint8_t len, ad_i2c_user_cb cb, void *user_data)
{

        ad_i2c_async_transact(dev, I2C_SND(&reg, 1),
                                I2C_SND_ST(val, len),
                                I2C_CB1(cb, user_data),
                                I2C_END);
}

/*
 * Read sensor register asynchronously
 */
static inline void read_reg_async(i2c_device dev, uint8_t reg, uint8_t *val, uint8_t len, ad_i2c_user_cb cb, void *user_data)
{
        /*
         * Reading sensor register consist of writing register number and reading it's contents.
         * Do this by preparing transaction that will generate write and read.
         * This demo uses callback that will signal event so task can be resumed after read.
         */
        ad_i2c_async_transact(dev, I2C_SND(&reg, 1),
                                I2C_RCV(val, len),
                                I2C_CB1(cb, user_data),
                                I2C_END);
}
/*
 * Write sensor register synchronously with user supplied event
 */
static int write_reg_event(i2c_device dev, uint8_t reg, const uint8_t *val, uint8_t len,
                                                                                i2c_event *event)
{

        reset_event(event);
        write_reg_async(dev, reg, val, len, signal_event, event);
        wait_for_event(event);
        return event->error;
}

static int read_reg_event(i2c_device dev, uint8_t reg, uint8_t *val, uint8_t len, i2c_event *event)
{
        reset_event(event);

        read_reg_async(dev, reg, val, len, signal_event, event);
        wait_for_event(event);

        return event->error;
}

bool IsBitSet(uint8_t num, int bit)
{
    return 1 == ( (num >> bit) & 1);
}



void query_busy() {
        uint8_t b = 0x01;

        dev = ad_i2c_open(IT7257); /* Open selected device */
        ad_i2c_device_acquire(dev);

        do {
          read_reg_event(dev, INDEX_CMD_READ, &b ,sizeof(b), &i2c_signal);
         // printf("busy\r\n");
        } while (b == 0x01);

        ad_i2c_device_release(dev);
        ad_i2c_close(dev);
}

void touch_init(void)
{
        printf("init touch\r\n");

        init_event(&i2c_signal);

        OS_DELAY_MS(10);
        query_busy();

        set_interrupt();

}


void whoami() {
       reset_event(&i2c_signal);

       uint8_t hello = 0x00;

       dev = ad_i2c_open(IT7257); // Open selected device
       ad_i2c_device_acquire(dev);
       write_reg_event(dev, INDEX_CMD_WRITE, &hello, sizeof(hello), &i2c_signal);

       uint8_t response[9] = {0x00};
       read_reg_event(dev, INDEX_CMD_READ, response, sizeof(response), &i2c_signal);
       ad_i2c_device_release(dev);
       ad_i2c_close(dev);

       printf("device: %c%c%c%c%c%c%c\n\r", response[1],response[2],response[3],response[4],response[5],response[6], response[7]);
}

void set_interrupt() {
        printf("set interrupt\r\n");
        uint8_t pucData[4];
        pucData[0] = 0x02;
        pucData[1] = 0x04;

        reset_event(&i2c_signal);
        OS_DELAY_MS(10);
        query_busy();
        OS_DELAY_MS(10);

        dev = ad_i2c_open(IT7257); /* Open selected device */

        ad_i2c_device_acquire(dev);

        write_reg_event(dev, INDEX_CMD_WRITE, pucData, sizeof(pucData), &i2c_signal);

        ad_i2c_device_release(dev);

        ad_i2c_close(dev);
}

void pollTouch() {

        //printf("pollTouch\r\n");

        OS_DELAY_MS(10);
        query_busy();
        uint8_t result = 0x00;
        start_query(&result);

        //if the 8th bit is set to 1 there is point/gesture/touch data available
        if (result & 0x80) {
                get_touch_sample();
        }
}
void start_query(uint8_t *result) {
        uint8_t res = 0x00;

        reset_event(&i2c_signal);

        dev = ad_i2c_open(IT7257); /* Open selected device */
        ad_i2c_device_acquire(dev);

        read_reg_event(dev, INDEX_QUERY_READ, &res ,sizeof(res), &i2c_signal);
       // printf("query %i\r\n",res);
        memcpy(result, &res, sizeof(res));

        ad_i2c_device_release(dev);
        ad_i2c_close(dev);
}

unsigned int hadTouch = 0;

void get_touch_sample() {
      // printf("get sample\r\n");

       uint8_t pointData[14] = {0x00};

       reset_event(&i2c_signal);

       dev = ad_i2c_open(IT7257); /* Open selected device */
       ad_i2c_device_acquire(dev);
       read_reg_event(dev, INDEX_POINT_READ, pointData, sizeof(pointData), &i2c_signal);
       ad_i2c_device_release(dev);
       ad_i2c_close(dev);

       //uint8_t x = pointData[2];
       //uint8_t y = pointData[4];

       //printf("Point data: %i %i %i %i %i %i % i% i\n\r", pointData[0] ,pointData[1],pointData[2],pointData[3],pointData[4],pointData[5],pointData[6], pointData[7]);
       if (pointData[2] != 0) { //touch down
               hadTouch = 1;
             //  printf("x: %i y: %i", pointData[2],pointData[4]);
               uint8_t points = {pointData[2],pointData[4]};
               setTouch(240-pointData[2], 240-pointData[4]);

       } else { //touch up?
               hadTouch = 0;
               OS_TASK_NOTIFY_FROM_ISR(getDisplayTaskHandle(), UPDATE_TOUCH_MASK, OS_NOTIFY_SET_BITS);
       }
       //return points;
}

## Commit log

2020-01-09 Added housing and dock stl
    [bottom_v9.stl, dock1.stl, top_v7.stl]
2020-01-14 Added Touch connector to PCB
    [Actuators-SchDoc.sch, Actuators.SchDoc, BLE-SchDoc.sch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]
2020-02-03 Updated housing STL
    [top_v8.stl]
2020-02-04 Corrected touch connector orientation
    [Actuators.SchDoc, Sensors.SchDoc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]
2020-02-04 Moved PCB files to the correct folders
    [smarchWatch_V5.GBL, smarchWatch_V5.GBO, smarchWatch_V5.GBP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]
2020-02-04 Fixed minor clearance issue in pcb
    [smarchWatch_V5.PcbDoc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]
2020-02-04 Added board parameters
2020-02-28 Added BOM
    [BillOfMaterials.xlsx]
2020-02-28 Updated BOM
    [BillOfMaterials.xlsx]
2020-02-29 Turned on accelerometer, turned off touch. Added rtt. Updated date code in display task
2020-02-29 Changed platform_devices to turn on the accelerometer and the touch off
